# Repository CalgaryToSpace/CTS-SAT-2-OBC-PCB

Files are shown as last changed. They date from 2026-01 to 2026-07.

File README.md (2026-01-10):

# CTS-SAT-2-OBC-PCB

This is the design repository for the CTS-SAT-2 onboard computer (OBC) PCB.

This OBC is host to an STM32 and several flash chips, and interfaces with all other electrical components on the 3U CubeSat.

## Repository Contents

* OBC PCB (KiCad; in progress) 
* STM32CubeIDE Pinout/IOC configuration (not yet done)

## Contributors

* Nadeem M ([DeemDeem52](https://github.com/DeemDeem52))
* Others

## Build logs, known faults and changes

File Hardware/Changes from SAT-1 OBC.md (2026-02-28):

# Changes from SAT-1 OBC

* RP2040 added as co-processor. ANT connections are through this processor instead of through the STM32.
   * SPI1 on the STM32 has been re-assigned to the RP2040 for simplicity of notation, and SPI2 on the STM32 has been assigned to the flash memory / FRAM (though the GPIO chip-select lines remain the same).
		* (Rationale: this way SPI1 on the RP2040 is connected to SPI1 of the STM32. SPI0 on the RP2040 is not connected to anything.)
   * The RP2040 has been assigned its own oscillator and flash memory. This could change in future.
   * ANT I2C2 and I2C3 lines from the STM32 have been reassigned to I2C0 and I2C1 from the RP2040.
		* To simplify notation, ADCS I2C1 has been reassigned to I2C2, and Temperature Sensor I2C4 had been reassigned to I2C3.
		* (Rationale: this way there is only one each of I2C0, 1, 2, and 3 on the board instead of having 2x I2C1 connected to different things)
* Temperature sensor STDS75 has gone obsolete. Using manufacturer-recommended replacement STTS22H instead.
* FRAM memory chip CY15B108QN-40LPXI has gone obsolete. Chips have been removed because they were unused in CTS-SAT-1. 
* A connector (Picoblade, 4-wide) has been added for the Optical Downlink Payload, which communicates via USART2. 
* Header pins for jumpers have been placed on the 3V3, 5V, and 12V lines where they enter the OBC to allow for easier current measurement.
* On the PC104 header, H1 pins 33 and 35 have been assigned to the ADCS UART connections. They are presently unconnected.
* STM32 25MHz clock ECS-TXO-2520-33-250-AN-TR originally had no stock available at DigiKey, but now has 515. No changes have been made to this.
* STM32 Reset Switch KH-6X6X4.3H-STM is very difficult to find. Replacing with C&K PTS526SK15SMTR2-LFS, which is available at DigiKey.

# Info from Design Reviews
* MPI expects to downlink a lot of data, which might require additional or larger flash memory modules. 
* DP on RP2040 to reset it to a known state in case of bad code?

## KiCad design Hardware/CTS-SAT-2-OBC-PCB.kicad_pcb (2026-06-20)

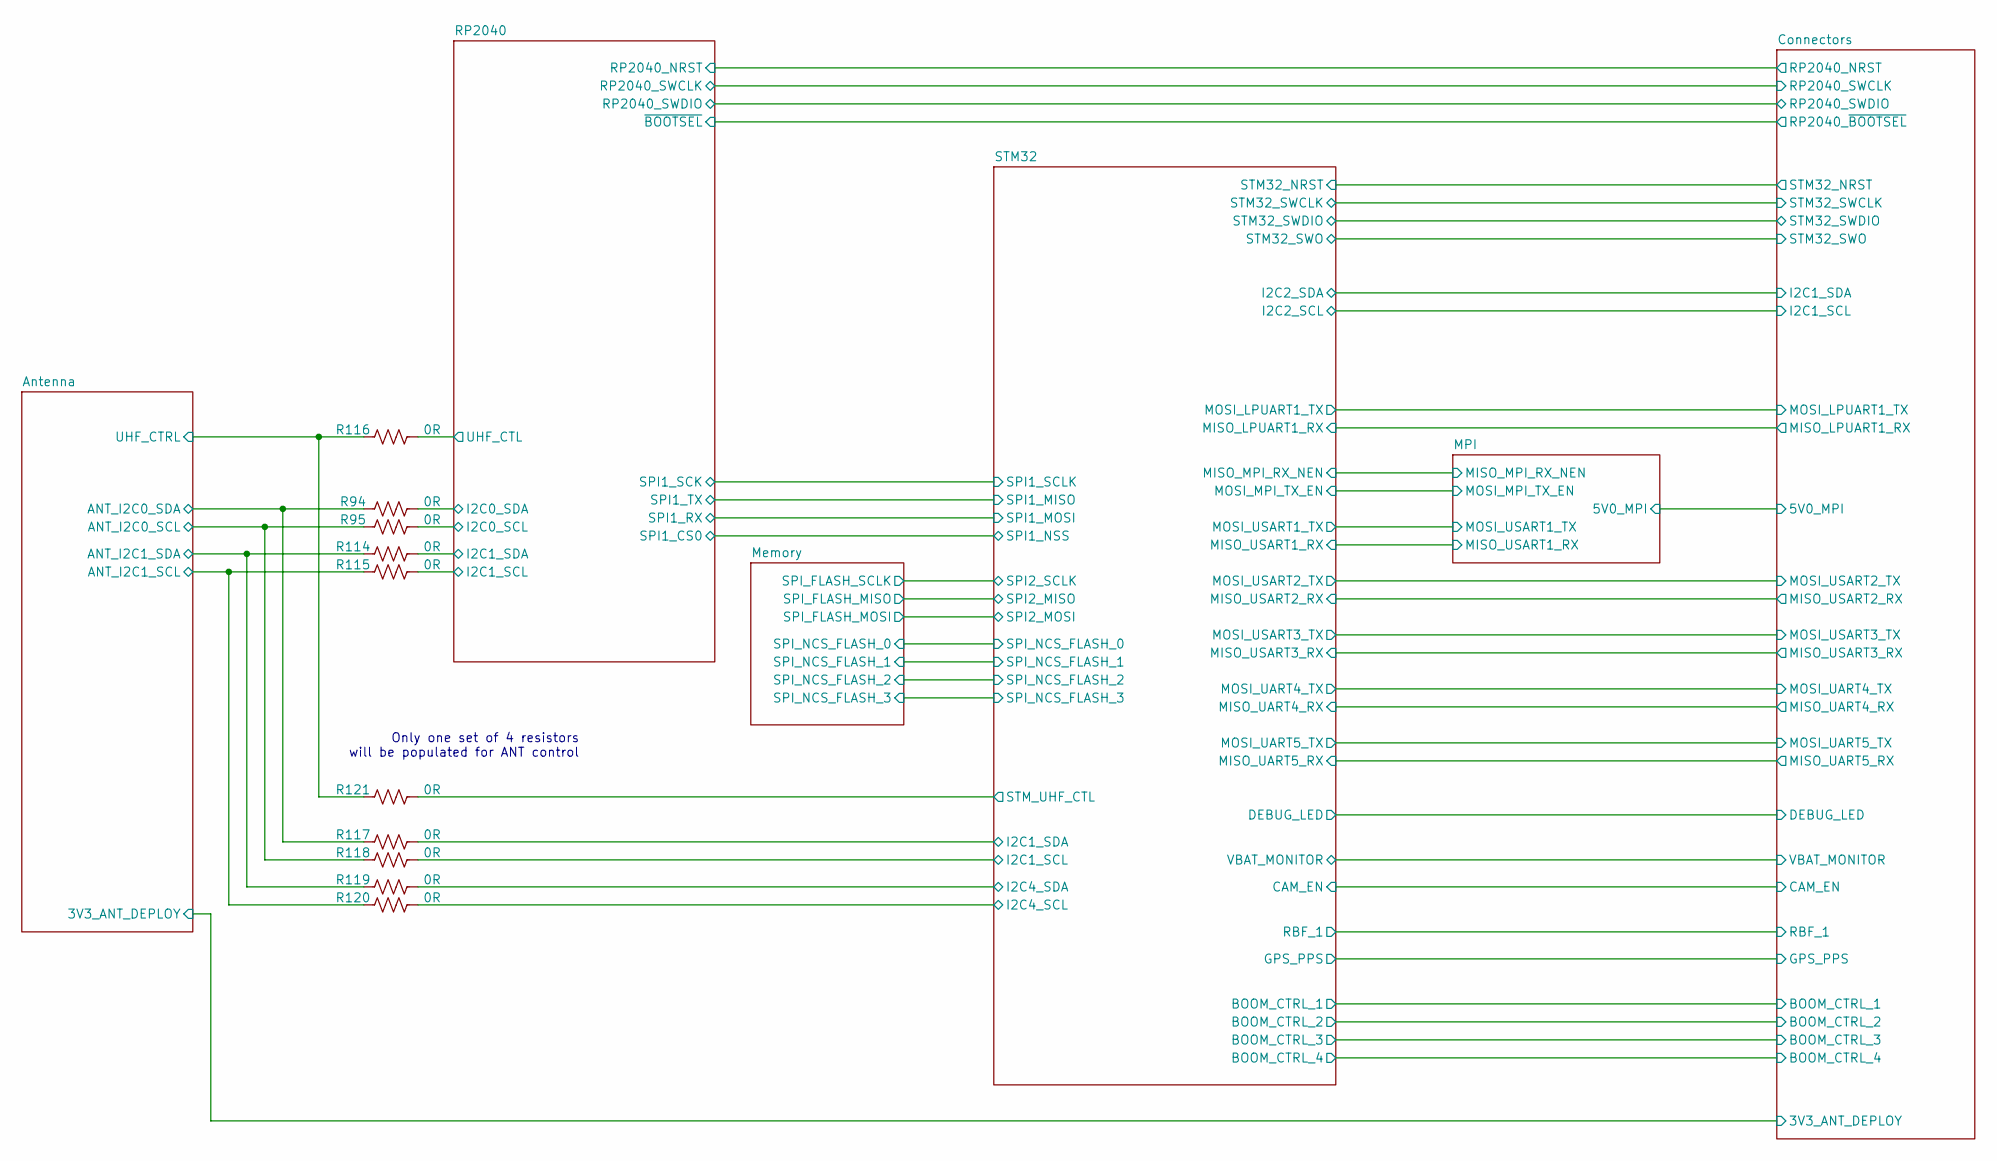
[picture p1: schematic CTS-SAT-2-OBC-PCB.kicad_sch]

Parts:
R94, R95, R114, R115, R116, R117, R118, R119, R120, R121: 0R; R_0603_1608Metric

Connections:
/Antenna/ANT_I2C0_SCL: R95.1, R118.1; also elsewhere on the board
/Antenna/ANT_I2C0_SDA: R94.1, R117.1; also elsewhere on the board
/Antenna/ANT_I2C1_SCL: R115.1, R120.1; also elsewhere on the board
/Antenna/ANT_I2C1_SDA: R114.1, R119.1; also elsewhere on the board
/Antenna/UHF_CTRL: R116.1, R121.1; also elsewhere on the board
/RP2040/I2C0_SCL: R95.2; also elsewhere on the board
/RP2040/I2C0_SDA: R94.2; also elsewhere on the board
/RP2040/I2C1_SCL: R115.2; also elsewhere on the board
/RP2040/I2C1_SDA: R114.2; also elsewhere on the board
/RP2040/UHF_CTL: R116.2; also elsewhere on the board
/STM32/I2C1_SCL: R118.2; also elsewhere on the board
/STM32/I2C1_SDA: R117.2; also elsewhere on the board
/STM32/I2C4_SCL: R120.2; also elsewhere on the board
/STM32/I2C4_SDA: R119.2; also elsewhere on the board
/STM32/STM_UHF_CTL: R121.2

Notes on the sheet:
Only one set of 4 resistors will be populated for ANT control

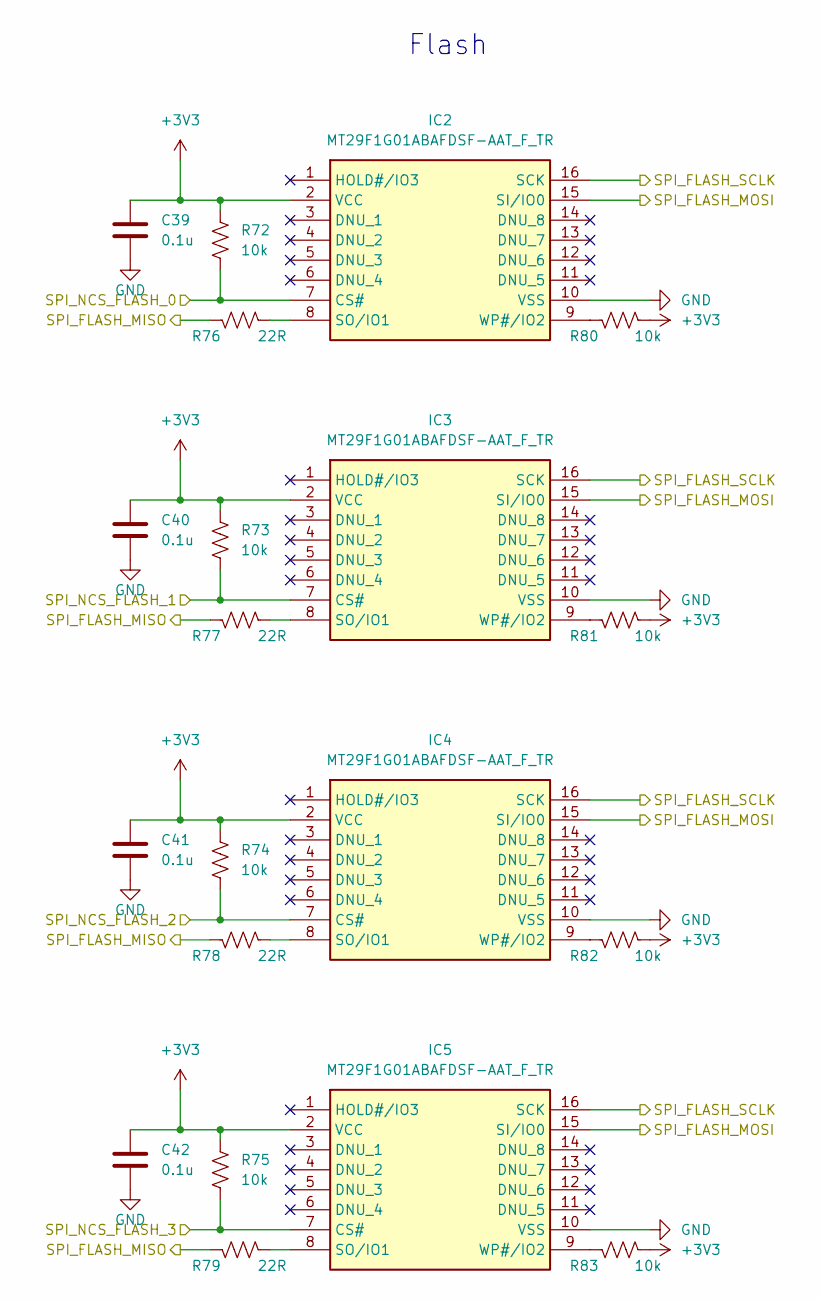
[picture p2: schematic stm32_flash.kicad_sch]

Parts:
C39, C40, C41, C42: 0.1u; C_0603_1608Metric
IC2, IC3, IC4, IC5: MT29F1G01ABAFDSF-AAT_F_TR; SOIC-16W_7.5x10.3mm_P1.27mm; Mouser Part Number 340-312330-REEL
R72, R73, R74, R75, R80, R81, R82, R83: 10k; R_0603_1608Metric
R76, R77, R78, R79: 22R; R_0603_1608Metric

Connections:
+3V3: C39.2, C40.2, C41.2, C42.2, IC2.2 (VCC), IC3.2 (VCC), IC4.2 (VCC), IC5.2 (VCC), R72.1, R73.1, R74.1, R75.1, R80.2, R81.2, R82.2, R83.2; also elsewhere on the board
/Memory/SPI_FLASH_MISO: R76.2, R77.2, R78.2, R79.2; also elsewhere on the board
/Memory/SPI_FLASH_MOSI: IC2.15 (SI/IO0), IC3.15 (SI/IO0), IC4.15 (SI/IO0), IC5.15 (SI/IO0); also elsewhere on the board
/Memory/SPI_FLASH_SCLK: IC2.16 (SCK), IC3.16 (SCK), IC4.16 (SCK), IC5.16 (SCK); also elsewhere on the board
/Memory/SPI_NCS_FLASH_0: IC2.7 (CS#), R72.2; also elsewhere on the board
/Memory/SPI_NCS_FLASH_1: IC3.7 (CS#), R73.2; also elsewhere on the board
/Memory/SPI_NCS_FLASH_2: IC4.7 (CS#), R74.2; also elsewhere on the board
/Memory/SPI_NCS_FLASH_3: IC5.7 (CS#), R75.2; also elsewhere on the board
GND: C39.1, C40.1, C41.1, C42.1, IC2.10 (VSS), IC3.10 (VSS), IC4.10 (VSS), IC5.10 (VSS); also elsewhere on the board
unnamed: IC2.8 (SO/IO1), R76.1
unnamed: IC2.9 (WP#/IO2), R80.1
unnamed: IC3.8 (SO/IO1), R77.1
unnamed: IC3.9 (WP#/IO2), R81.1
unnamed: IC4.8 (SO/IO1), R78.1
unnamed: IC4.9 (WP#/IO2), R82.1
unnamed: IC5.8 (SO/IO1), R79.1
unnamed: IC5.9 (WP#/IO2), R83.1

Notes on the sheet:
Flash

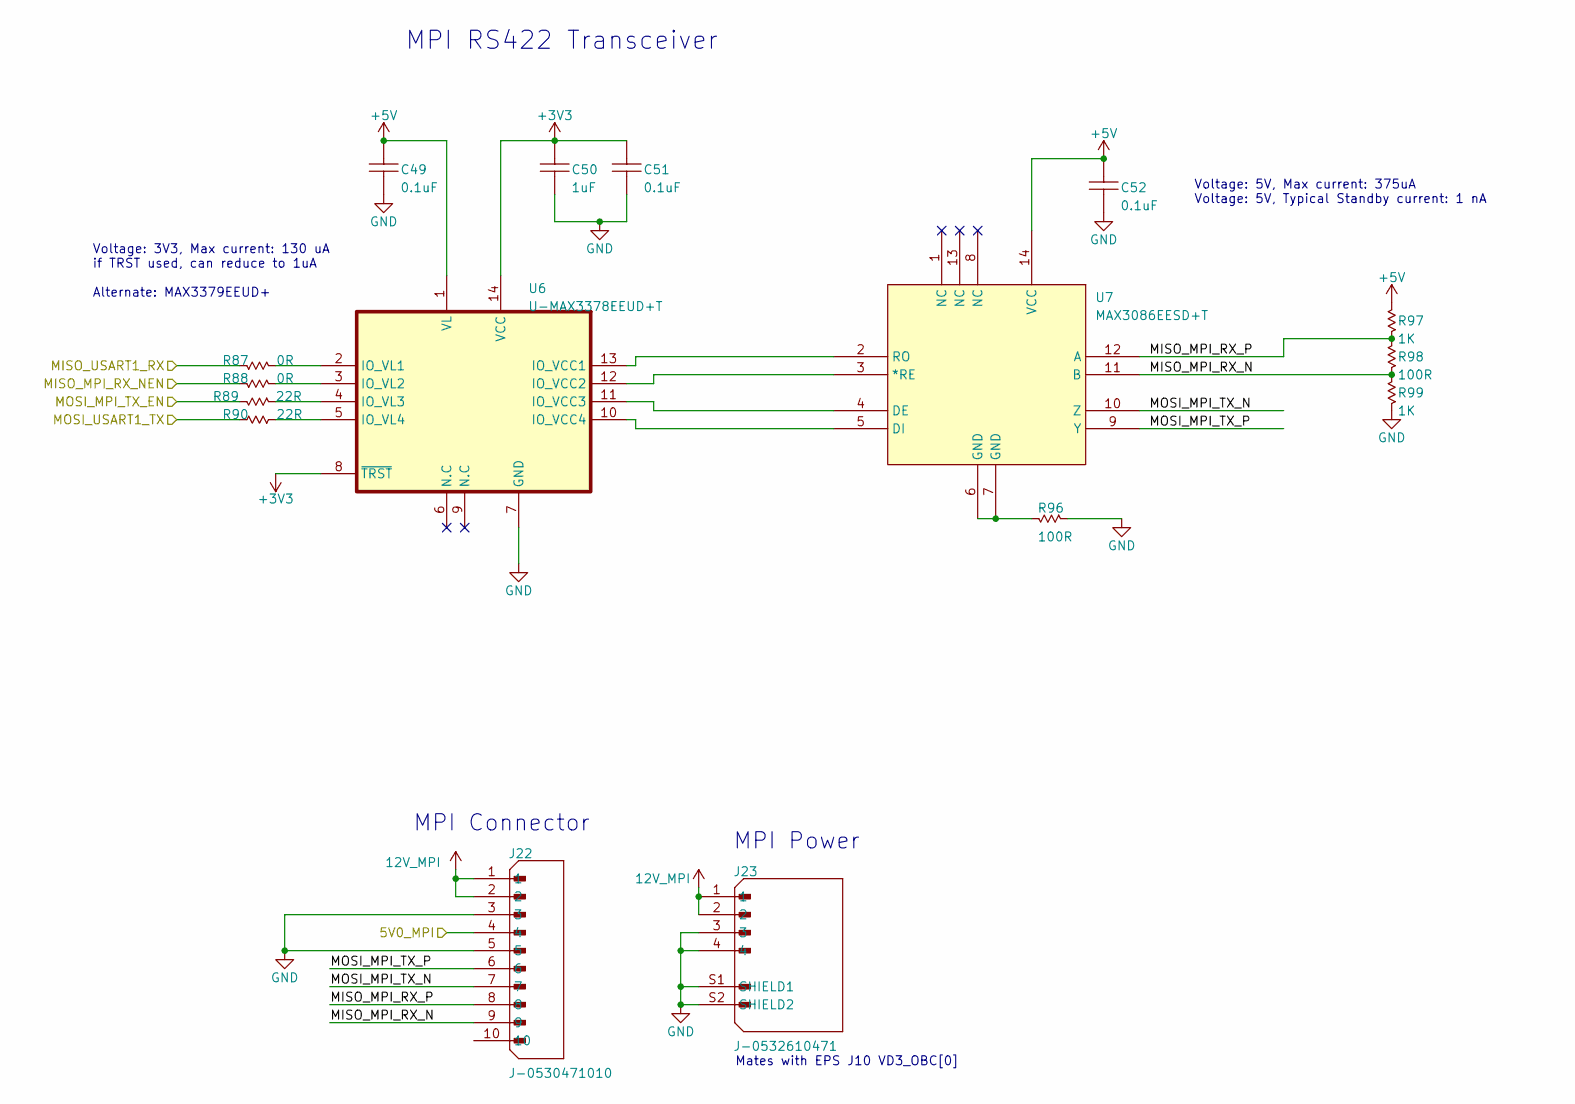
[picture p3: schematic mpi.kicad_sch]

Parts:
C49, C51, C52: 0.1uF; C_0603_1608Metric; RATED VOLTAGE 25; MANUFACTURER PART # GCJ188R71E104KA12D
C50: 1uF; C_0603_1608Metric; MANUFACTURER PART # CC0603KRX7R8BB105
J22: J-0530471010; MANUFACTURER PART # 0530471010
J23: J-0532610471; J-53261-0471; MANFACTURER PART # 0532610471
R87, R88: 0R; R_0603_1608Metric; MANUFACTURER PART # RMCF0603ZT0R00
R89, R90: 22R; R_0603_1608Metric; MANUFACTURER PART # RR0816Q-220-D
R96, R98: 100R; R_0603_1608Metric; MANUFACTURER PART # RR08P100DCT-ND
R97, R99: 1K; R_0603_1608Metric; MANUFACTURER PART # CPF0603F1K0C1
U6: U-MAX3378EEUD+T; MANUFACTURER PART # MAX3378EEUD+T; LCSC PART # C143441
U7: MAX3086EESD+T; U-MAX3086EESD+T; MANUFACTURER PART # MAX3086EESD+T; LCSC PART # C2671104

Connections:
12V_MPI: J22.1, J22.2, J23.1, J23.2
+3V3: C50.2, C51.1, U6.8 (~TRST), U6.14 (VCC); also elsewhere on the board
+5V: C49.1, C52.1, R97.2, U6.1 (VL), U7.14 (VCC); also elsewhere on the board
/Connectors/5V0_MPI: J22.4; also elsewhere on the board
/MPI/MISO_MPI_RX_N: J22.9, R98.1, R99.2, U7.11 (B)
/MPI/MISO_MPI_RX_NEN: R88.1; also elsewhere on the board
/MPI/MISO_MPI_RX_P: J22.8, R97.1, R98.2, U7.12 (A)
/MPI/MISO_USART1_RX: R87.1; also elsewhere on the board
/MPI/MOSI_MPI_TX_EN: R89.2; also elsewhere on the board
/MPI/MOSI_MPI_TX_N: J22.7, U7.10 (Z)
/MPI/MOSI_MPI_TX_P: J22.6, U7.9 (Y)
/MPI/MOSI_USART1_TX: R90.2; also elsewhere on the board
GND: C49.2, C50.1, C51.2, C52.2, J22.3, J22.5, J23.3, J23.4, J23.S1 (SHIELD1), J23.S2 (SHIELD2), R96.1, R99.1, U6.7 (GND); also elsewhere on the board
unnamed: R96.2, U7.6 (GND), U7.7 (GND)
unnamed: U6.13 (IO_VCC1), U7.2 (RO)
unnamed: U6.12 (IO_VCC2), U7.3 (*RE)
unnamed: U6.11 (IO_VCC3), U7.4 (DE)
unnamed: U6.10 (IO_VCC4), U7.5 (DI)
unnamed: R87.2, U6.2 (IO_VL1)
unnamed: R88.2, U6.3 (IO_VL2)
unnamed: R89.1, U6.4 (IO_VL3)
unnamed: R90.1, U6.5 (IO_VL4)

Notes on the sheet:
Voltage: 3V3, Max current: 130 uA if TRST used, can reduce to 1uA Alternate: MAX3379EEUD+
Voltage: 5V, Max current: 375uA Voltage: 5V, Typical Standby current: 1 nA
Mates with EPS J10 VD3_OBC[0]
MPI Connector
MPI Power
MPI RS422 Transceiver

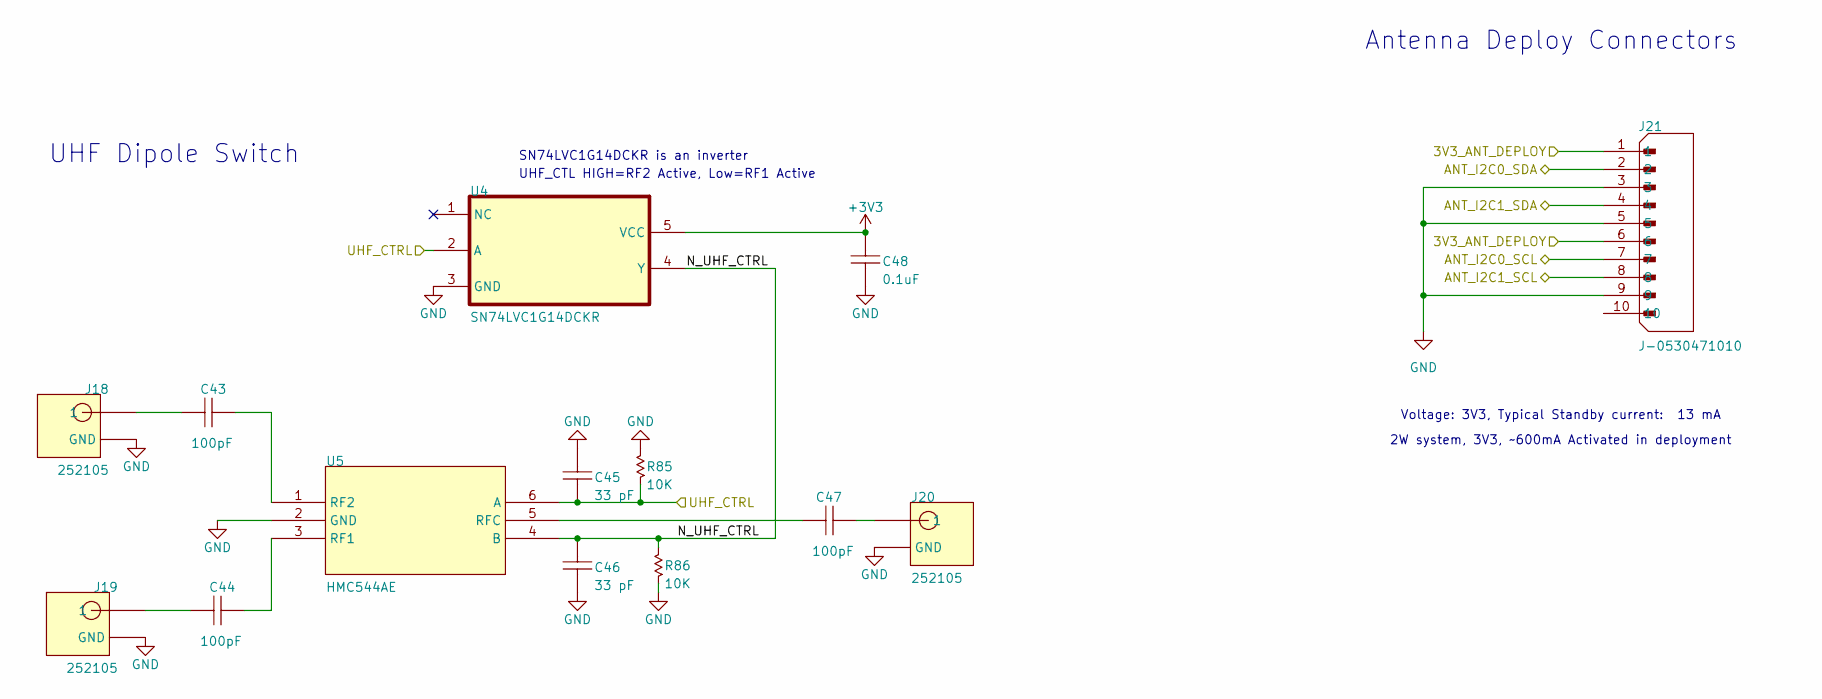
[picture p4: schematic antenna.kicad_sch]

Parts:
C43, C44, C47: 100pF; C_0603_1608Metric; MANUFACTURER PART # CC0603KRX7R9BB101
C45, C46: 33 pF; C_0603_1608Metric; MANUFACTURER PART # C0603C330K5RAC7867
C48: 0.1uF; C_0603_1608Metric; RATED VOLTAGE 25; MANUFACTURER PART # GCJ188R71E104KA12D
J18, J19, J20: 252105; J-252105; MANUFACTURER PART # 252105
J21: J-0530471010; MANUFACTURER PART # 0530471010
R85, R86: 10K; R_0603_1608Metric; MANUFACTURER PART # CPF0603B10KE
U4: SN74LVC1G14DCKR; U-SN74LVC1G14DCKR; MANUFACTURER PART # SN74LVC1G14DCKR; LCSC PART # C35740
U5: HMC544AE; U-HMC544AETR; MANUFACTURER PART # HMC544AETR; LCSC PART # C579555

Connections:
+3V3: C48.2, U4.5 (VCC); also elsewhere on the board
/Antenna/3V3_ANT_DEPLOY: J21.1, J21.6; also elsewhere on the board
/Antenna/ANT_I2C0_SCL: J21.7; also elsewhere on the board
/Antenna/ANT_I2C0_SDA: J21.2; also elsewhere on the board
/Antenna/ANT_I2C1_SCL: J21.8; also elsewhere on the board
/Antenna/ANT_I2C1_SDA: J21.4; also elsewhere on the board
/Antenna/N_UHF_CTRL: C46.2, R86.2, U4.4 (Y), U5.4 (B)
/Antenna/UHF_CTRL: C45.1, R85.1, U4.2 (A), U5.6 (A); also elsewhere on the board
GND: C45.2, C46.1, C48.1, J18.0 (GND), J19.0 (GND), J20.0 (GND), J21.3, J21.5, J21.9, R85.2, R86.1, U4.3 (GND), U5.2 (GND); also elsewhere on the board
unnamed: C43.1, J18.1
unnamed: C44.1, J19.1
unnamed: C47.2, J20.1
unnamed: C44.2, U5.3 (RF1)
unnamed: C43.2, U5.1 (RF2)
unnamed: C47.1, U5.5 (RFC)

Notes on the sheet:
Antenna Deploy Connectors
Voltage: 3V3, Typical Standby current: 13 mA
SN74LVC1G14DCKR is an inverter
UHF Dipole Switch
UHF_CTL HIGH=RF2 Active, Low=RF1 Active
2W system, 3V3, ~600mA Activated in deployment

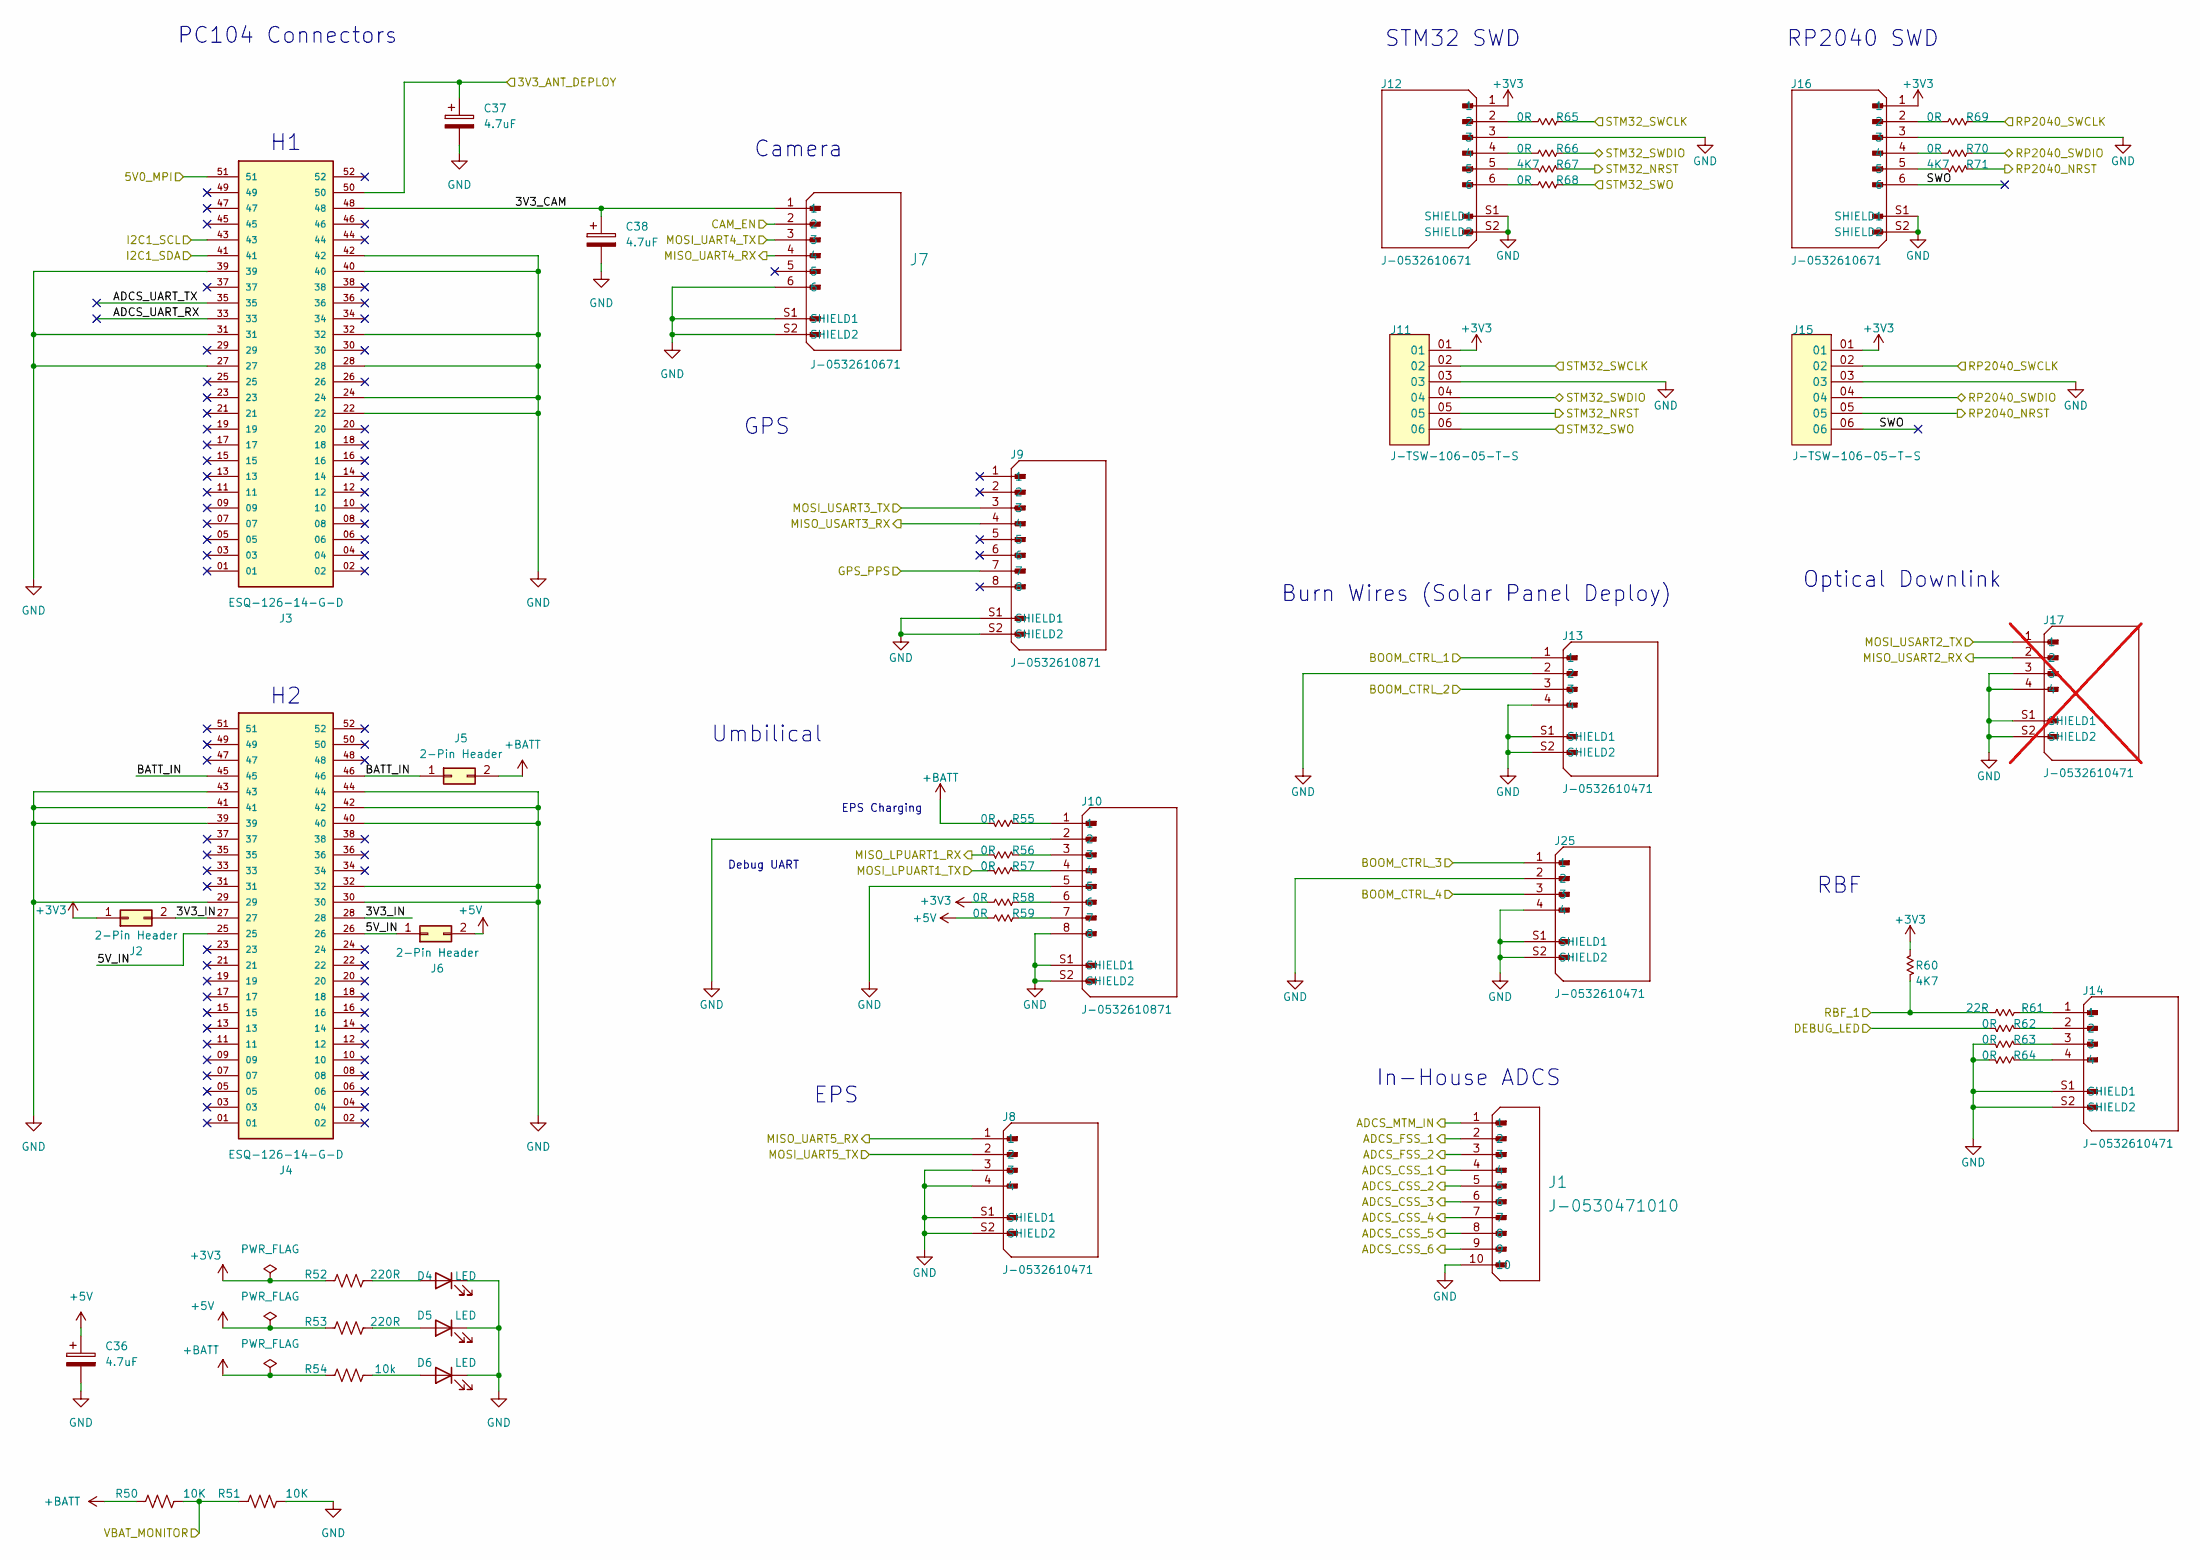
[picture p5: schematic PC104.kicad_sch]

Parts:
C36, C37, C38: 4.7uF; C_1206_3216Metric
D4, D5, D6: LED; D-SML-D12U1WT86
J1: J-0530471010; Manufacturer Part # 0530471010
J2, J5, J6: 2-Pin Header; PinHeader_1x02_P1.27mm_Vertical
J3, J4: ESQ-126-14-G-D; SAMTEC_ESQ-126-14-G-D; PARTREV R
J7: J-0532610671; Manfacturer Part # 0532610671
J8, J13, J14, J25: J-0532610471; J-53261-0471; MANFACTURER PART # 0532610471
J9, J10: J-0532610871; J-532610871; MANFACTURER PART # 0532610871
J11, J15: J-TSW-106-05-T-S; MANUFACTURER PART # TSW-106-05-T-S
J12, J16: J-0532610671; MANFACTURER PART # 0532610671
J17: J-0532610471; J-53261-0471; MANFACTURER PART # 0532610471; not fitted
R50, R51: 10K; R_0603_1608Metric
R52, R53: 220R; R_0603_1608Metric
R54: 10k; R_0603_1608Metric
R55, R56, R57, R58, R59, R62, R63, R64, R65, R66, R68, R69, R70: 0R; R_0603_1608Metric; MANUFACTURER PART # RMCF0603ZT0R00
R60, R67, R71: 4K7; R_0603_1608Metric; MANUFACTURER PART # CR0603-FX-4701ELF
R61: 22R; R_0603_1608Metric; MANUFACTURER PART # RR0816Q-220-D

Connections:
+3V3: J2.1, J11.01, J12.1, J15.01, J16.1, R52.1, R58.2, R60.2; also elsewhere on the board
+5V: C36.1, J6.2, R53.1, R59.2; also elsewhere on the board
+BATT: J5.2, R50.1, R54.1, R55.1
/Antenna/3V3_ANT_DEPLOY: C37.1, J3.50; also elsewhere on the board
/Connectors/3V3_CAM: C38.1, J3.48, J7.1
/Connectors/3V3_IN: J2.2, J4.27, J4.28
/Connectors/5V0_MPI: J3.51; also elsewhere on the board
/Connectors/5V_IN: J4.25, J4.26, J6.1
/Connectors/ADCS_CSS_1: J1.4
/Connectors/ADCS_CSS_2: J1.5
/Connectors/ADCS_CSS_3: J1.6
/Connectors/ADCS_CSS_4: J1.7
/Connectors/ADCS_CSS_5: J1.8
/Connectors/ADCS_CSS_6: J1.9
/Connectors/ADCS_FSS_1: J1.2
/Connectors/ADCS_FSS_2: J1.3
/Connectors/ADCS_MTM_IN: J1.1
/Connectors/ADCS_UART_RX: J3.33
/Connectors/ADCS_UART_TX: J3.35
/Connectors/BATT_IN: J4.45, J4.46, J5.1
/Connectors/BOOM_CTRL_1: J13.1; also elsewhere on the board
/Connectors/BOOM_CTRL_2: J13.3; also elsewhere on the board
/Connectors/BOOM_CTRL_3: J25.1; also elsewhere on the board
/Connectors/BOOM_CTRL_4: J25.3; also elsewhere on the board
/Connectors/CAM_EN: J7.2; also elsewhere on the board
/Connectors/DEBUG_LED: R62.1; also elsewhere on the board
/Connectors/GPS_PPS: J9.7; also elsewhere on the board
/Connectors/MISO_LPUART1_RX: R56.1; also elsewhere on the board
/Connectors/MISO_UART4_RX: J7.4; also elsewhere on the board
/Connectors/MISO_UART5_RX: J8.1; also elsewhere on the board
/Connectors/MISO_USART3_RX: J9.4; also elsewhere on the board
/Connectors/MOSI_LPUART1_TX: R57.1; also elsewhere on the board
/Connectors/MOSI_UART4_TX: J7.3; also elsewhere on the board
/Connectors/MOSI_UART5_TX: J8.2; also elsewhere on the board
/Connectors/MOSI_USART3_TX: J9.3; also elsewhere on the board
/Connectors/RBF_1: R60.1, R61.1; also elsewhere on the board
/Connectors/RP2040_NRST: J15.05, R71.1; also elsewhere on the board
/Connectors/RP2040_SWCLK: J15.02, R69.1; also elsewhere on the board
/Connectors/RP2040_SWDIO: J15.04, R70.1; also elsewhere on the board
/Connectors/STM32_NRST: J11.05, R67.1; also elsewhere on the board
/Connectors/STM32_SWCLK: J11.02, R65.1; also elsewhere on the board
/Connectors/STM32_SWDIO: J11.04, R66.1; also elsewhere on the board
/Connectors/STM32_SWO: J11.06, R68.1; also elsewhere on the board
/Connectors/SWO: J15.06, J16.6
/Connectors/VBAT_MONITOR: R50.2, R51.1; also elsewhere on the board
/STM32/I2C2_SCL: J3.43; also elsewhere on the board
/STM32/I2C2_SDA: J3.41; also elsewhere on the board
GND: C36.2, C37.2, C38.2, D4.1 (K), D5.1 (K), D6.1 (K), J1.10, J3.22, J3.24, J3.27, J3.28, J3.31, J3.32, J3.39, J3.40, J3.42, J4.29, J4.30, J4.32, J4.39, J4.40, J4.41, J4.42, J4.43, J4.44, J7.6, J7.S1 (SHIELD1), J7.S2 (SHIELD2), J8.3, J8.4, J8.S1 (SHIELD1), J8.S2 (SHIELD2), J9.S1 (SHIELD1), J9.S2 (SHIELD2), J10.2, J10.5, J10.8, J10.S1 (SHIELD1), J10.S2 (SHIELD2), J11.03, J12.3, J12.S1 (SHIELD1), J12.S2 (SHIELD2), J13.2, J13.4, J13.S1 (SHIELD1), J13.S2 (SHIELD2), J14.S1 (SHIELD1), J14.S2 (SHIELD2), J15.03, J16.3, J16.S1 (SHIELD1), J16.S2 (SHIELD2), J17.3, J17.4, J17.S1 (SHIELD1), J17.S2 (SHIELD2), J25.2, J25.4, J25.S1 (SHIELD1), J25.S2 (SHIELD2), R51.2, R63.1, R64.1; also elsewhere on the board
unnamed: D4.2 (A), R52.2
unnamed: D5.2 (A), R53.2
unnamed: D6.2 (A), R54.2
unnamed: J10.1, R55.2
unnamed: J10.3, R56.2
unnamed: J10.4, R57.2
unnamed: J10.6, R58.1
unnamed: J10.7, R59.1
unnamed: J12.2, R65.2
unnamed: J12.4, R66.2
unnamed: J12.5, R67.2
unnamed: J12.6, R68.2
unnamed: J14.1, R61.2
unnamed: J14.2, R62.2
unnamed: J14.3, R63.2
unnamed: J14.4, R64.2
unnamed: J16.2, R69.2
unnamed: J16.4, R70.2
unnamed: J16.5, R71.2

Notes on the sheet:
PC104 Connectors
RP2040 SWD
RBF
Debug UART
Burn Wires (Solar Panel Deploy)
Optical Downlink
Camera
GPS
EPS
In-House ADCS
Umbilical
EPS Charging
STM32 SWD

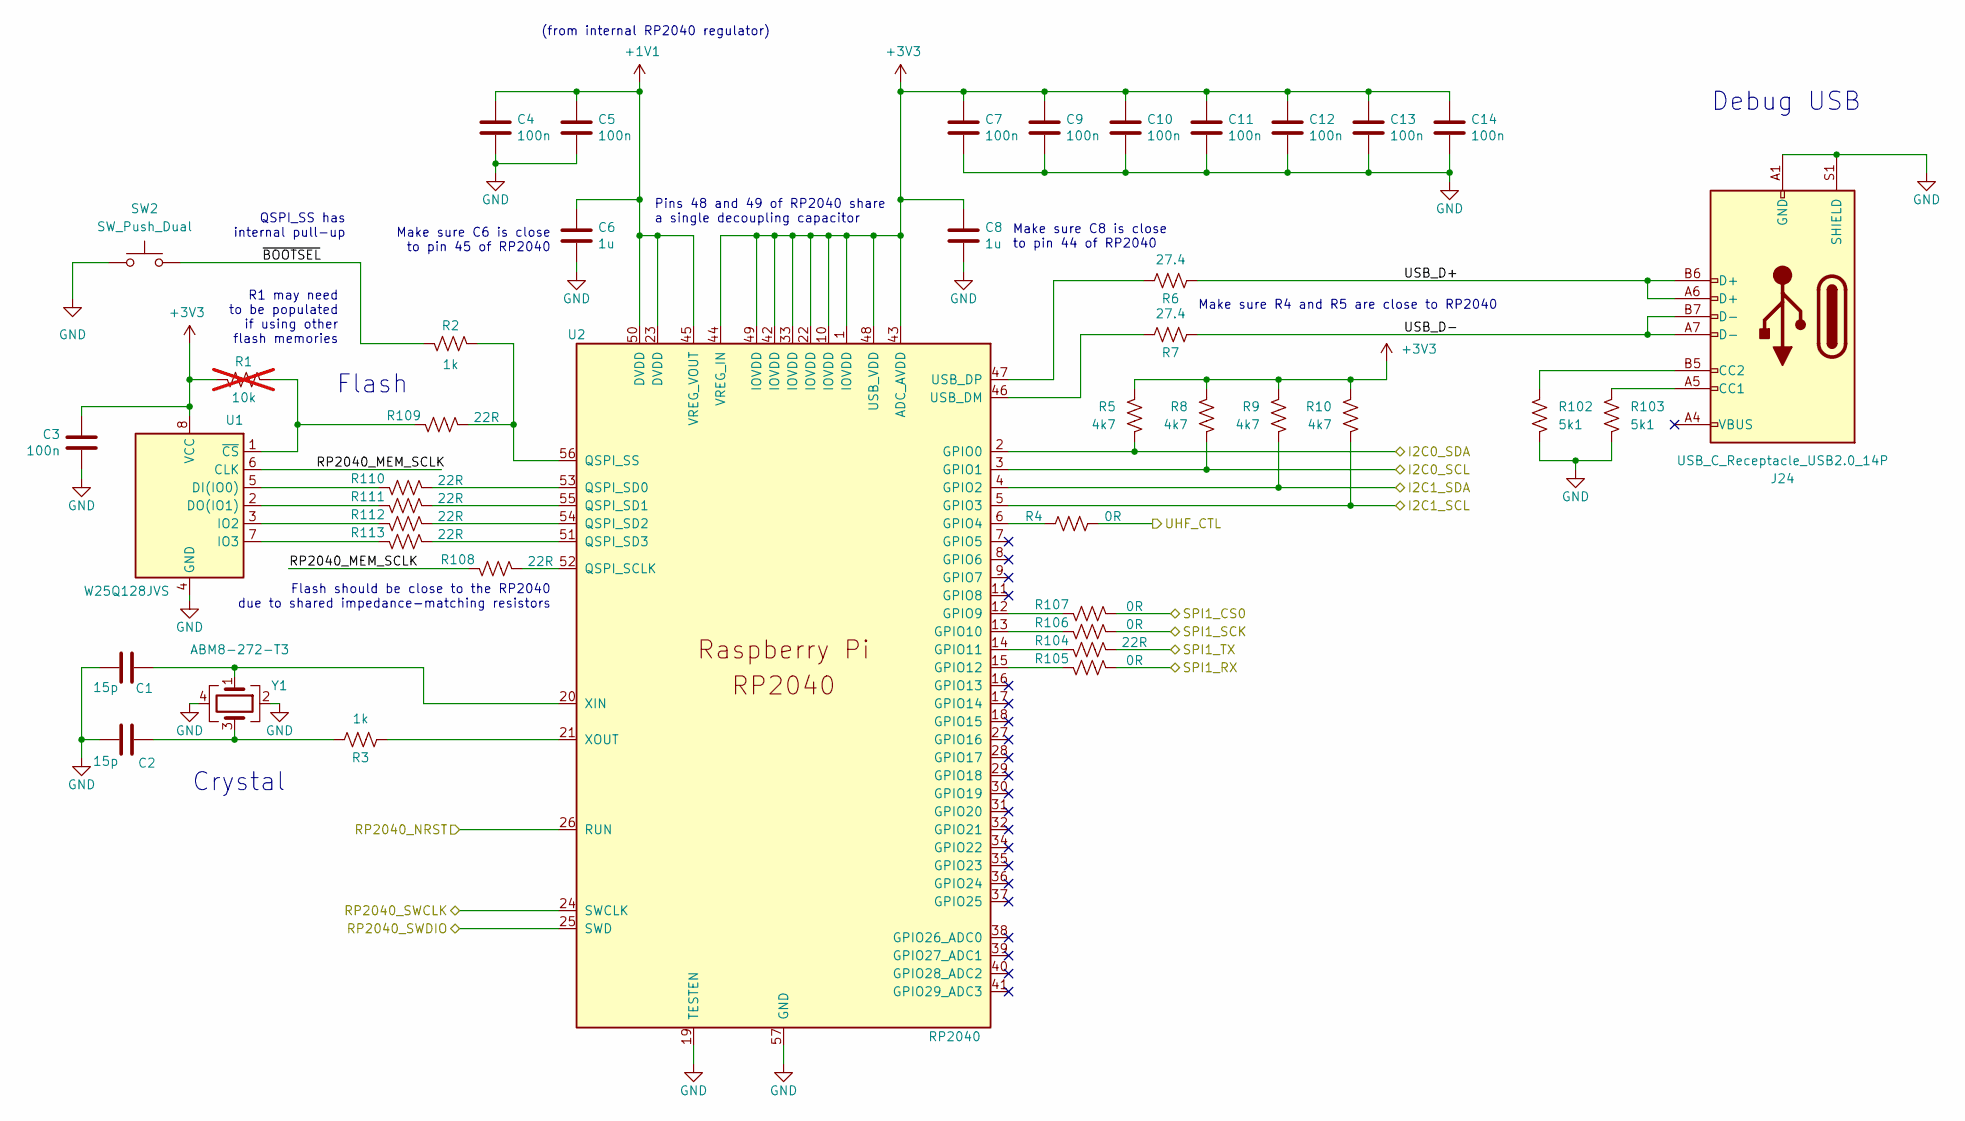
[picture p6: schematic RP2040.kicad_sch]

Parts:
C1, C2: 15p; C_0402_1005Metric
C3, C4, C5, C7, C9, C10, C11, C12, C13, C14: 100n; C_0402_1005Metric
C6, C8: 1u; C_0402_1005Metric
J24: USB_C_Receptacle_USB2.0_14P; USB_C_Receptacle_JAE_DX07S024WJ3R400
R1: 10k; R_0402_1005Metric; not fitted
R2, R3: 1k; R_0402_1005Metric
R4, R105, R106, R107: 0R; R_0603_1608Metric
R5, R8, R9, R10: 4k7; R_0603_1608Metric
R6, R7: 27.4; R_0402_1005Metric
R102, R103: 5k1; R_0603_1608Metric
R104, R108, R109, R110, R111, R112, R113: 22R; R_0603_1608Metric
SW2: SW_Push_Dual; SMT_FS
U1: W25Q128JVS; SOIC-8_5.23x5.23mm_P1.27mm
U2: RP2040; RP2040-QFN-56
Y1: ABM8-272-T3; Crystal_SMD_3225-4Pin_3.2x2.5mm

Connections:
+1V1: C4.1, C5.1, C6.1, U2.23 (DVDD), U2.45 (VREG_VOUT), U2.50 (DVDD)
+3V3: C3.1, C7.1, C8.1, C9.1, C10.1, C11.1, C12.1, C13.1, C14.1, R1.2, R5.1, R8.1, R9.1, R10.1, U1.8 (VCC), U2.1 (IOVDD), U2.10 (IOVDD), U2.22 (IOVDD), U2.33 (IOVDD), U2.42 (IOVDD), U2.43 (ADC_AVDD), U2.44 (VREG_IN), U2.48 (USB_VDD), U2.49 (IOVDD); also elsewhere on the board
/Connectors/RP2040_NRST: U2.26 (RUN); also elsewhere on the board
/Connectors/RP2040_SWCLK: U2.24 (SWCLK); also elsewhere on the board
/Connectors/RP2040_SWDIO: U2.25 (SWD); also elsewhere on the board
/RP2040/I2C0_SCL: R8.2, U2.3 (GPIO1); also elsewhere on the board
/RP2040/I2C0_SDA: R5.2, U2.2 (GPIO0); also elsewhere on the board
/RP2040/I2C1_SCL: R10.2, U2.5 (GPIO3); also elsewhere on the board
/RP2040/I2C1_SDA: R9.2, U2.4 (GPIO2); also elsewhere on the board
/RP2040/RP2040_MEM_SCLK: R108.2, U1.6 (CLK)
/RP2040/SPI1_CS0: R107.1; also elsewhere on the board
/RP2040/SPI1_RX: R105.1; also elsewhere on the board
/RP2040/SPI1_SCK: R106.1; also elsewhere on the board
/RP2040/SPI1_TX: R104.1; also elsewhere on the board
/RP2040/UHF_CTL: R4.2; also elsewhere on the board
/RP2040/USB_D+: J24.A6 (D+), J24.B6 (D+), R6.1
/RP2040/USB_D-: J24.A7 (D-), J24.B7 (D-), R7.1
/RP2040/~BOOTSEL: R2.2, SW2.1
GND: C1.2, C2.2, C3.2, C4.2, C5.2, C6.2, C7.2, C8.2, C9.2, C10.2, C11.2, C12.2, C13.2, C14.2, J24.A1 (GND), J24.A12 (GND), J24.B1 (GND), J24.B12 (GND), J24.S1 (SHIELD), R102.2, R103.2, SW2.2, U1.4 (GND), U2.19 (TESTEN), U2.57 (GND), Y1.2, Y1.4; also elsewhere on the board
unnamed: C2.1, R3.2, Y1.3
unnamed: J24.A5 (CC1), R103.1
unnamed: J24.B5 (CC2), R102.1
unnamed: R110.2, U1.5 (DI(IO0))
unnamed: R111.2, U1.2 (DO(IO1))
unnamed: R112.2, U1.3 (IO2)
unnamed: R113.2, U1.7 (IO3)
unnamed: R1.1, R109.2, U1.1 (~CS)
unnamed: R4.1, U2.6 (GPIO4)
unnamed: R107.2, U2.12 (GPIO9)
unnamed: R106.2, U2.13 (GPIO10)
unnamed: R104.2, U2.14 (GPIO11)
unnamed: R105.2, U2.15 (GPIO12)
unnamed: R108.1, U2.52 (QSPI_SCLK)
unnamed: R110.1, U2.53 (QSPI_SD0)
unnamed: R111.1, U2.55 (QSPI_SD1)
unnamed: R112.1, U2.54 (QSPI_SD2)
unnamed: R113.1, U2.51 (QSPI_SD3)
unnamed: R2.1, R109.1, U2.56 (QSPI_SS)
unnamed: R7.2, U2.46 (USB_DM)
unnamed: R6.2, U2.47 (USB_DP)
unnamed: C1.1, U2.20 (XIN), Y1.1
unnamed: R3.1, U2.21 (XOUT)

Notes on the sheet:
Debug USB
Crystal
QSPI_SS has internal pull-up
Pins 48 and 49 of RP2040 share a single decoupling capacitor
Make sure R4 and R5 are close to RP2040
Make sure C6 is close to pin 45 of RP2040
(from internal RP2040 regulator)
R1 may need to be populated if using other flash memories
Flash should be close to the RP2040 due to shared impedance-matching resistors
Flash
Make sure C8 is close to pin 44 of RP2040

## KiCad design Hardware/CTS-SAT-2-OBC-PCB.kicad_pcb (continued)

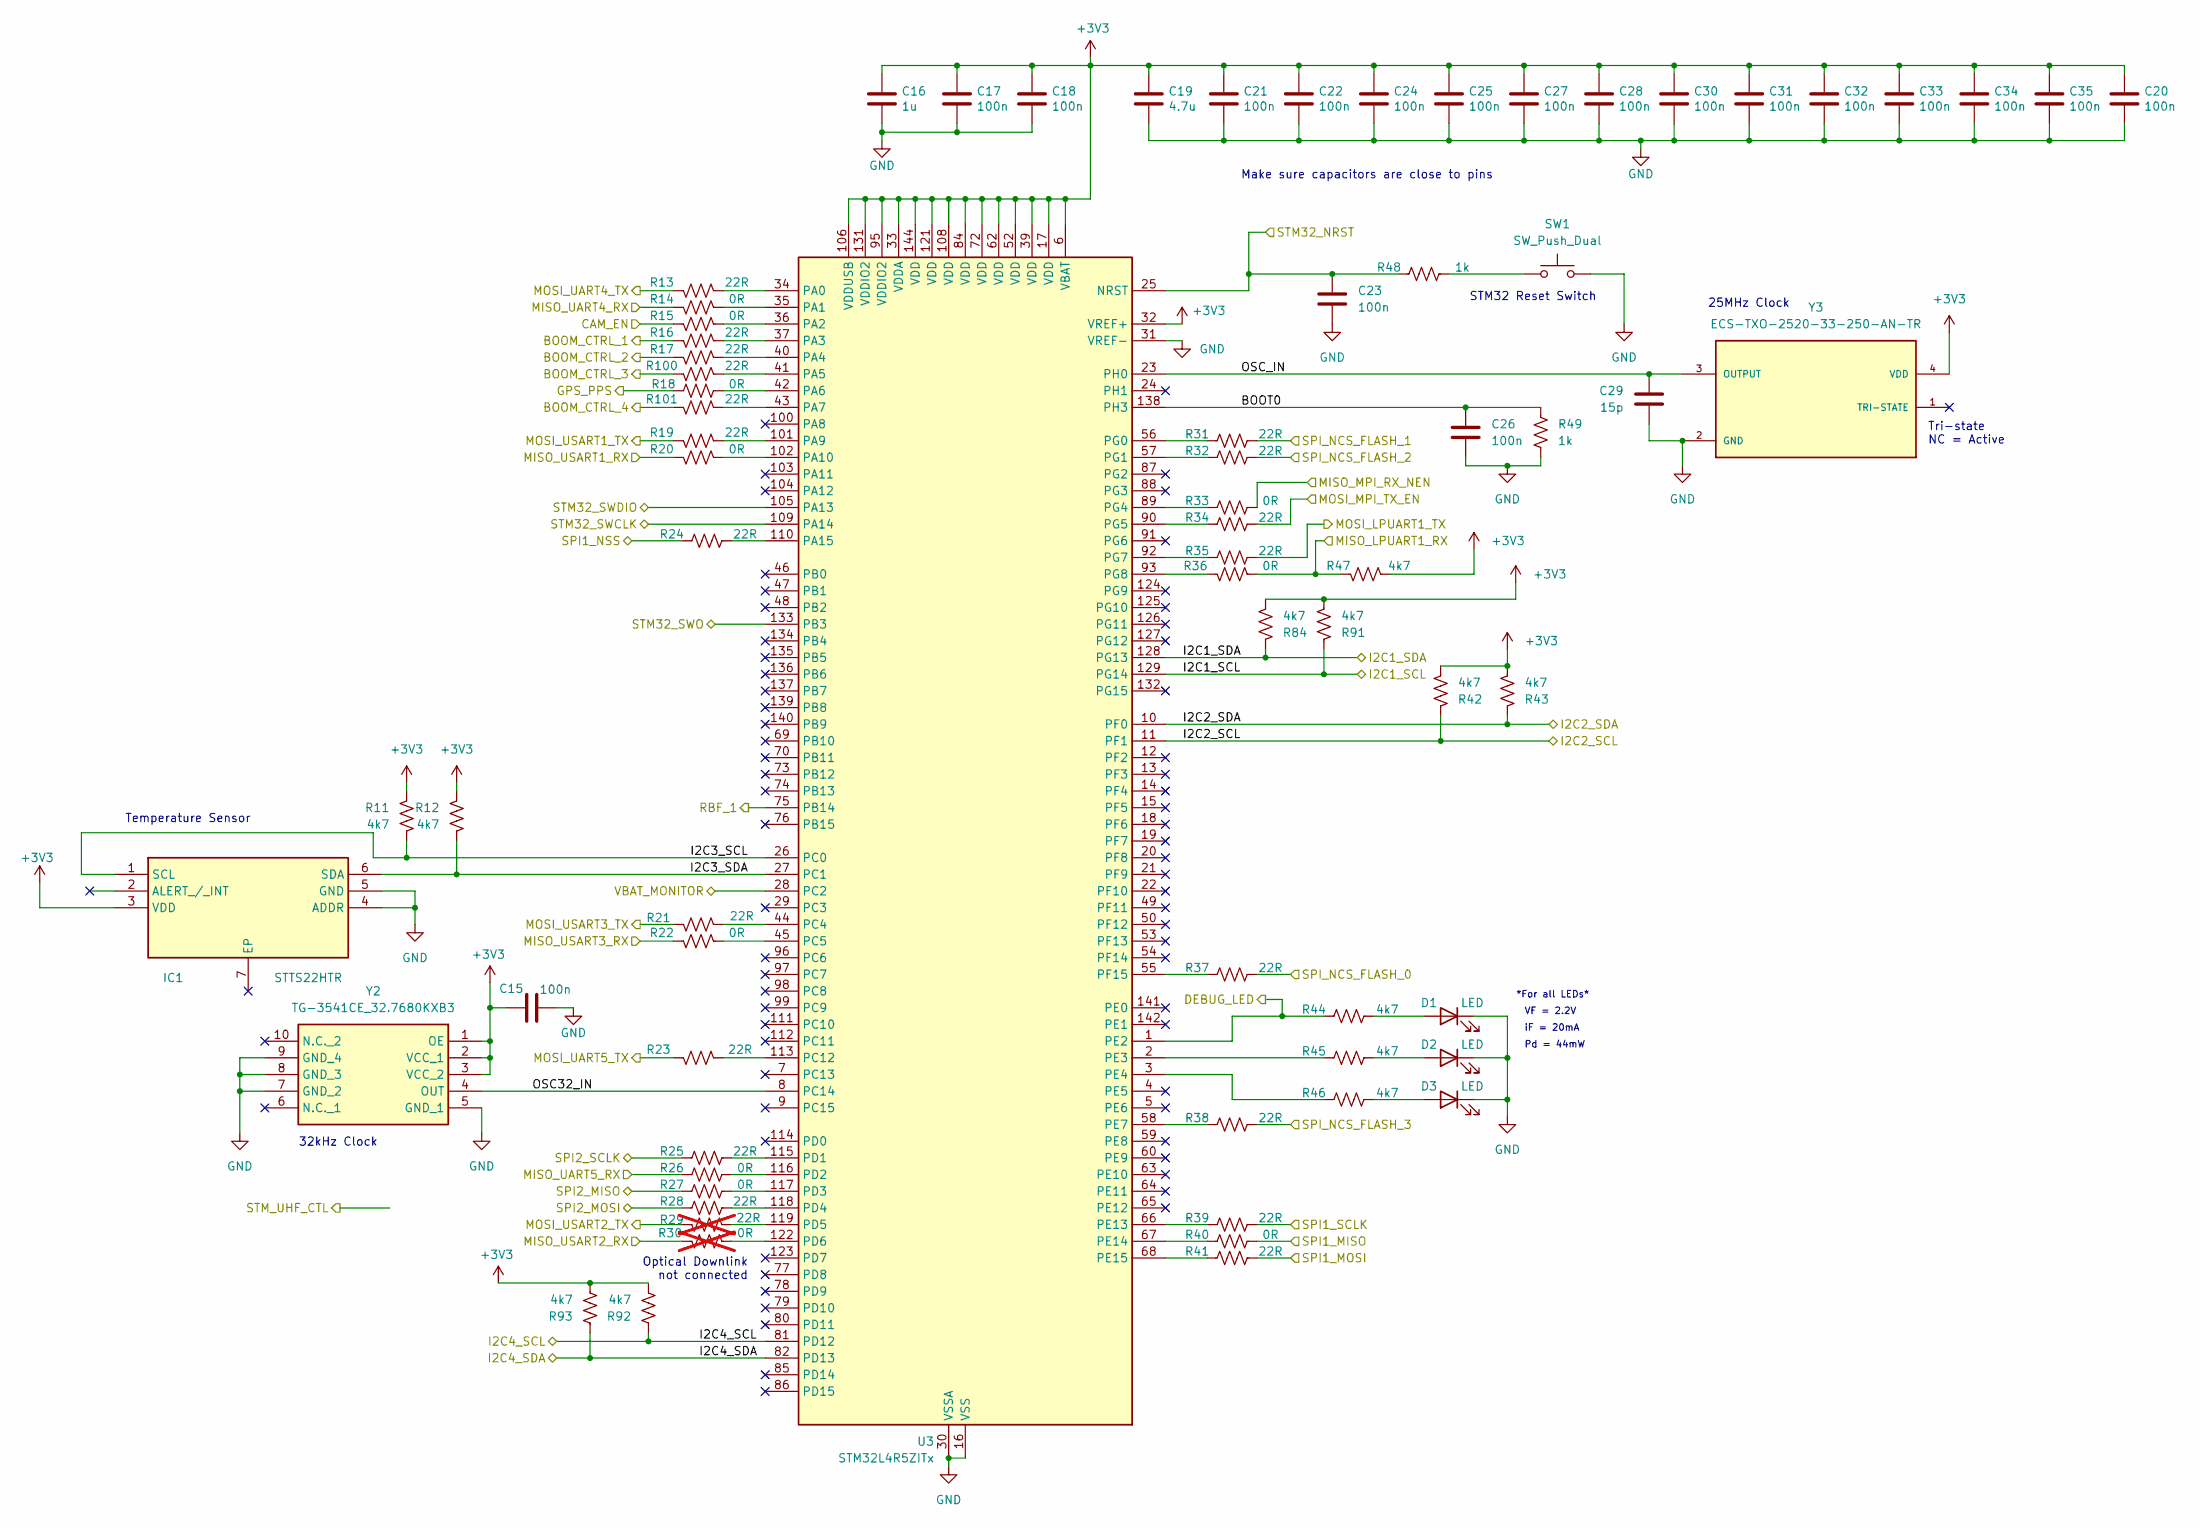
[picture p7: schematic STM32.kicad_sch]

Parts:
C15, C17, C18, C20, C21, C22, C24, C25, C27, C28, C30, C31, C32, C33, C34, C35: 100n; C_0402_1005Metric
C16: 1u; C_0402_1005Metric
C19: 4.7u; C_0402_1005Metric
C23, C26: 100n; C_0603_1608Metric
C29: 15p; C_0603_1608Metric
D1, D2, D3: LED; D-SML-D12U1WT86
IC1: STTS22HTR; SON65P200X200X55-7N-D; Manufacturer_Part_Number STTS22HTR; Mouser Part Number 511-STTS22HTR
R11, R12, R42, R43, R44, R45, R46, R47, R84, R91, R92, R93: 4k7; R_0603_1608Metric
R13, R16, R17, R19, R21, R23, R24, R25, R28, R31, R32, R34, R35, R37, R38, R39, R41, R100, R101: 22R; R_0603_1608Metric
R14, R15, R18, R20, R22, R26, R27, R33, R36, R40: 0R; R_0603_1608Metric
R29: 22R; R_0603_1608Metric; not fitted
R30: 0R; R_0603_1608Metric; not fitted
R48, R49: 1k; R_0603_1608Metric
SW1: SW_Push_Dual; SMT_FS
U3: STM32L4R5ZITx; LQFP-144_20x20mm_P0.5mm
Y2: TG-3541CE_32.7680KXB3; TG3541CE327680KXB3; Mouser Part Number 732-TG3541CE32768XB3
Y3: ECS-TXO-2520-33-250-AN-TR; OSC_ECS-TXO-2520-33-250-AN-TR; PARTREV 2017; DigiKey_Part_Number XC2258CT-ND

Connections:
+3V3: C15.1, C16.1, C17.1, C18.1, C19.1, C20.1, C21.1, C22.1, C24.1, C25.1, C27.1, C28.1, C30.1, C31.1, C32.1, C33.1, C34.1, C35.1, IC1.3 (VDD), R11.1, R12.1, R42.2, R43.2, R47.1, R84.2, R91.2, R92.2, R93.2, U3.6 (VBAT), U3.17 (VDD), U3.32 (VREF+), U3.33 (VDDA), U3.39 (VDD), U3.52 (VDD), U3.62 (VDD), U3.72 (VDD), U3.84 (VDD), U3.95 (VDDIO2), U3.106 (VDDUSB), U3.108 (VDD), U3.121 (VDD), U3.131 (VDDIO2), U3.144 (VDD), Y2.1 (OE), Y2.2 (VCC_1), Y2.3 (VCC_2), Y3.4 (VDD); also elsewhere on the board
/Connectors/BOOM_CTRL_1: R16.2; also elsewhere on the board
/Connectors/BOOM_CTRL_2: R17.2; also elsewhere on the board
/Connectors/BOOM_CTRL_3: R100.2; also elsewhere on the board
/Connectors/BOOM_CTRL_4: R101.2; also elsewhere on the board
/Connectors/CAM_EN: R15.2; also elsewhere on the board
/Connectors/DEBUG_LED: R44.1, U3.1 (PE2); also elsewhere on the board
/Connectors/GPS_PPS: R18.1; also elsewhere on the board
/Connectors/MISO_LPUART1_RX: R36.1, R47.2; also elsewhere on the board
/Connectors/MISO_UART4_RX: R14.2; also elsewhere on the board
/Connectors/MISO_UART5_RX: R26.1; also elsewhere on the board
/Connectors/MISO_USART3_RX: R22.2; also elsewhere on the board
/Connectors/MOSI_LPUART1_TX: R35.2; also elsewhere on the board
/Connectors/MOSI_UART4_TX: R13.2; also elsewhere on the board
/Connectors/MOSI_UART5_TX: R23.2; also elsewhere on the board
/Connectors/MOSI_USART3_TX: R21.2; also elsewhere on the board
/Connectors/RBF_1: U3.75 (PB14); also elsewhere on the board
/Connectors/STM32_NRST: C23.1, R48.1, U3.25 (NRST); also elsewhere on the board
/Connectors/STM32_SWCLK: U3.109 (PA14); also elsewhere on the board
/Connectors/STM32_SWDIO: U3.105 (PA13); also elsewhere on the board
/Connectors/STM32_SWO: U3.133 (PB3); also elsewhere on the board
/Connectors/VBAT_MONITOR: U3.28 (PC2); also elsewhere on the board
/MPI/MISO_MPI_RX_NEN: R33.2; also elsewhere on the board
/MPI/MISO_USART1_RX: R20.2; also elsewhere on the board
/MPI/MOSI_MPI_TX_EN: R34.2; also elsewhere on the board
/MPI/MOSI_USART1_TX: R19.2; also elsewhere on the board
/Memory/SPI_FLASH_MISO: R27.1; also elsewhere on the board
/Memory/SPI_FLASH_MOSI: R28.1; also elsewhere on the board
/Memory/SPI_FLASH_SCLK: R25.1; also elsewhere on the board
/Memory/SPI_NCS_FLASH_0: R37.2; also elsewhere on the board
/Memory/SPI_NCS_FLASH_1: R31.2; also elsewhere on the board
/Memory/SPI_NCS_FLASH_2: R32.2; also elsewhere on the board
/Memory/SPI_NCS_FLASH_3: R38.2; also elsewhere on the board
/RP2040/SPI1_CS0: R24.1; also elsewhere on the board
/RP2040/SPI1_RX: R41.2; also elsewhere on the board
/RP2040/SPI1_SCK: R39.2; also elsewhere on the board
/RP2040/SPI1_TX: R40.2; also elsewhere on the board
/STM32/BOOT0: C26.1, R49.1, U3.138 (PH3)
/STM32/I2C1_SCL: R91.1, U3.129 (PG14); also elsewhere on the board
/STM32/I2C1_SDA: R84.1, U3.128 (PG13); also elsewhere on the board
/STM32/I2C2_SCL: R42.1, U3.11 (PF1); also elsewhere on the board
/STM32/I2C2_SDA: R43.1, U3.10 (PF0); also elsewhere on the board
/STM32/I2C3_SCL: IC1.1 (SCL), R11.2, U3.26 (PC0)
/STM32/I2C3_SDA: IC1.6 (SDA), R12.2, U3.27 (PC1)
/STM32/I2C4_SCL: R92.1, U3.81 (PD12); also elsewhere on the board
/STM32/I2C4_SDA: R93.1, U3.82 (PD13); also elsewhere on the board
/STM32/OSC32_IN: U3.8 (PC14), Y2.4 (OUT)
/STM32/OSC_IN: C29.1, U3.23 (PH0), Y3.3 (OUTPUT)
GND: C15.2, C16.2, C17.2, C18.2, C19.2, C20.2, C21.2, C22.2, C23.2, C24.2, C25.2, C26.2, C27.2, C28.2, C29.2, C30.2, C31.2, C32.2, C33.2, C34.2, C35.2, D1.1 (K), D2.1 (K), D3.1 (K), IC1.4 (ADDR), IC1.5 (GND), R49.2, SW1.2, U3.16 (VSS), U3.30 (VSSA), U3.31 (VREF-), U3.38 (VSS), U3.51 (VSS), U3.61 (VSS), U3.71 (VSS), U3.83 (VSS), U3.94 (VSS), U3.107 (VSS), U3.120 (VSS), U3.130 (VSS), U3.143 (VSS), Y2.5 (GND_1), Y2.7 (GND_2), Y2.8 (GND_3), Y2.9 (GND_4), Y3.2 (GND); also elsewhere on the board
unnamed: D1.2 (A), R44.2
unnamed: D2.2 (A), R45.2
unnamed: D3.2 (A), R46.2
unnamed: R48.2, SW1.1
unnamed: R13.1, U3.34 (PA0)
unnamed: R14.1, U3.35 (PA1)
unnamed: R15.1, U3.36 (PA2)
unnamed: R16.1, U3.37 (PA3)
unnamed: R17.1, U3.40 (PA4)
unnamed: R100.1, U3.41 (PA5)
unnamed: R18.2, U3.42 (PA6)
unnamed: R101.1, U3.43 (PA7)
unnamed: R19.1, U3.101 (PA9)
unnamed: R20.1, U3.102 (PA10)
unnamed: R24.2, U3.110 (PA15)
unnamed: R21.1, U3.44 (PC4)
unnamed 168: R22.1, U3.45 (PC5); also elsewhere on the board
unnamed: R23.1, U3.113 (PC12)
unnamed: R25.2, U3.115 (PD1)
unnamed: R26.2, U3.116 (PD2)
unnamed: R27.2, U3.117 (PD3)
unnamed: R28.2, U3.118 (PD4)
unnamed: R29.1, U3.119 (PD5)
unnamed: R30.1, U3.122 (PD6)
unnamed: R45.1, U3.2 (PE3)
unnamed: R46.1, U3.3 (PE4)
unnamed: R38.1, U3.58 (PE7)
unnamed: R39.1, U3.66 (PE13)
unnamed: R40.1, U3.67 (PE14)
unnamed: R41.1, U3.68 (PE15)
unnamed: R37.1, U3.55 (PF15)
unnamed: R31.1, U3.56 (PG0)
unnamed: R32.1, U3.57 (PG1)
unnamed: R33.1, U3.89 (PG4)
unnamed: R34.1, U3.90 (PG5)
unnamed: R35.1, U3.92 (PG7)
unnamed: R36.2, U3.93 (PG8)

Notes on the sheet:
Optical Downlink not connected
32kHz Clock
25MHz Clock
VF = 2.2V
STM32 Reset Switch
Tri-state NC = Active
Make sure capacitors are close to pins
Pd = 44mW
*For all LEDs*
Temperature Sensor
iF = 20mA

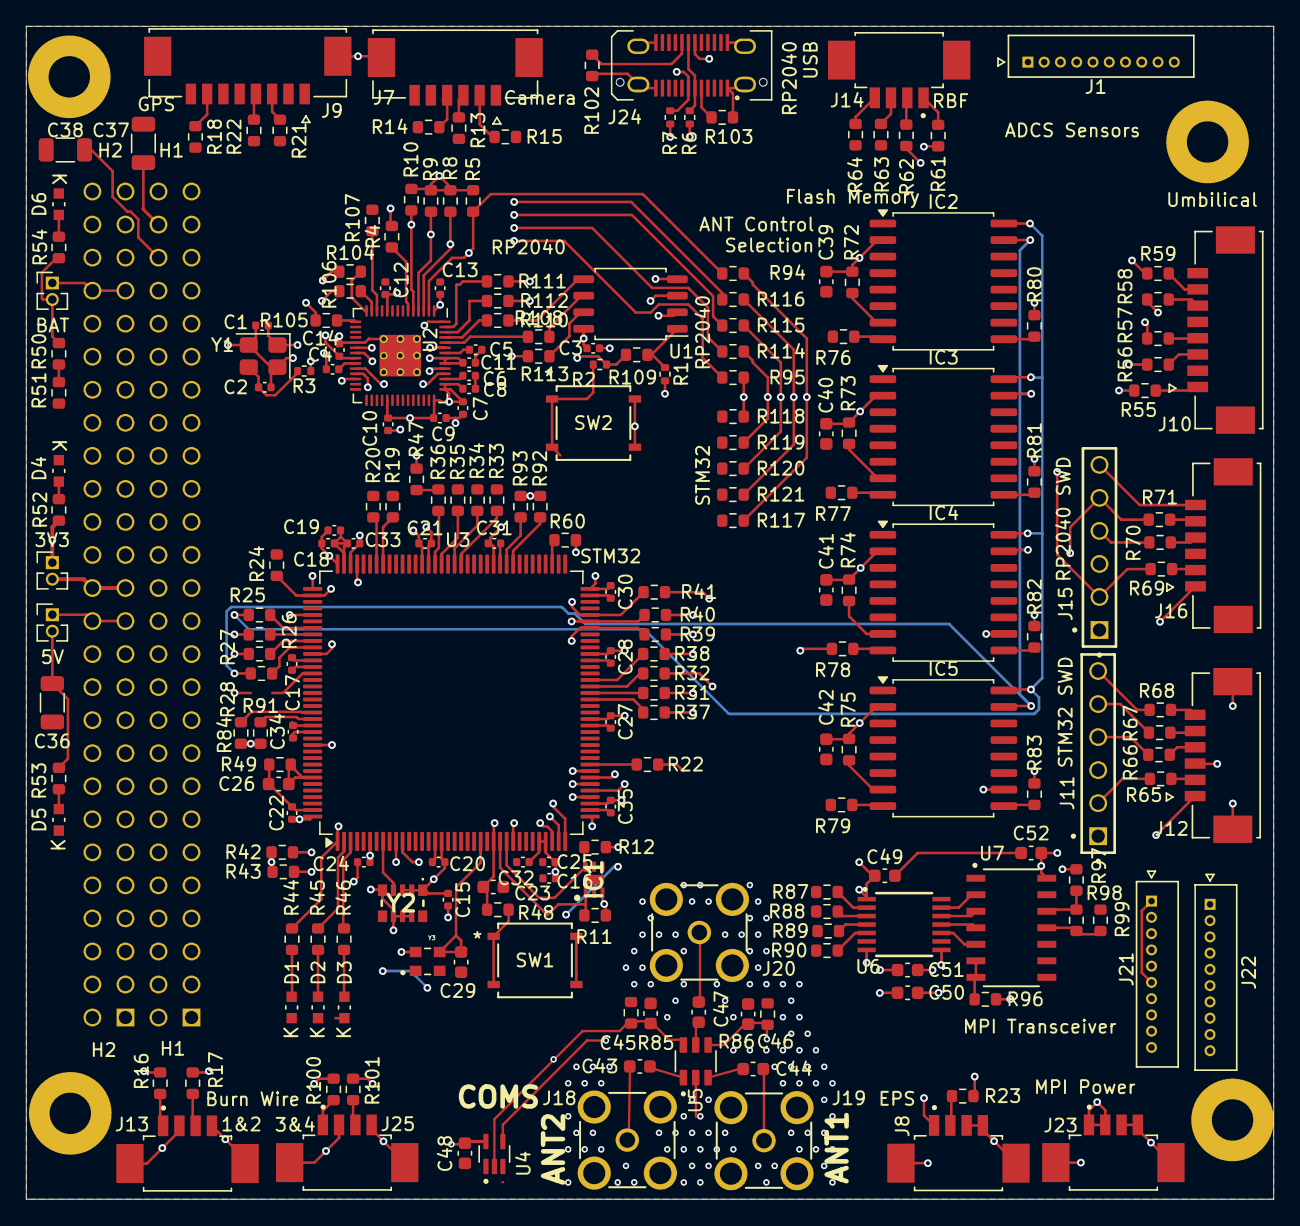
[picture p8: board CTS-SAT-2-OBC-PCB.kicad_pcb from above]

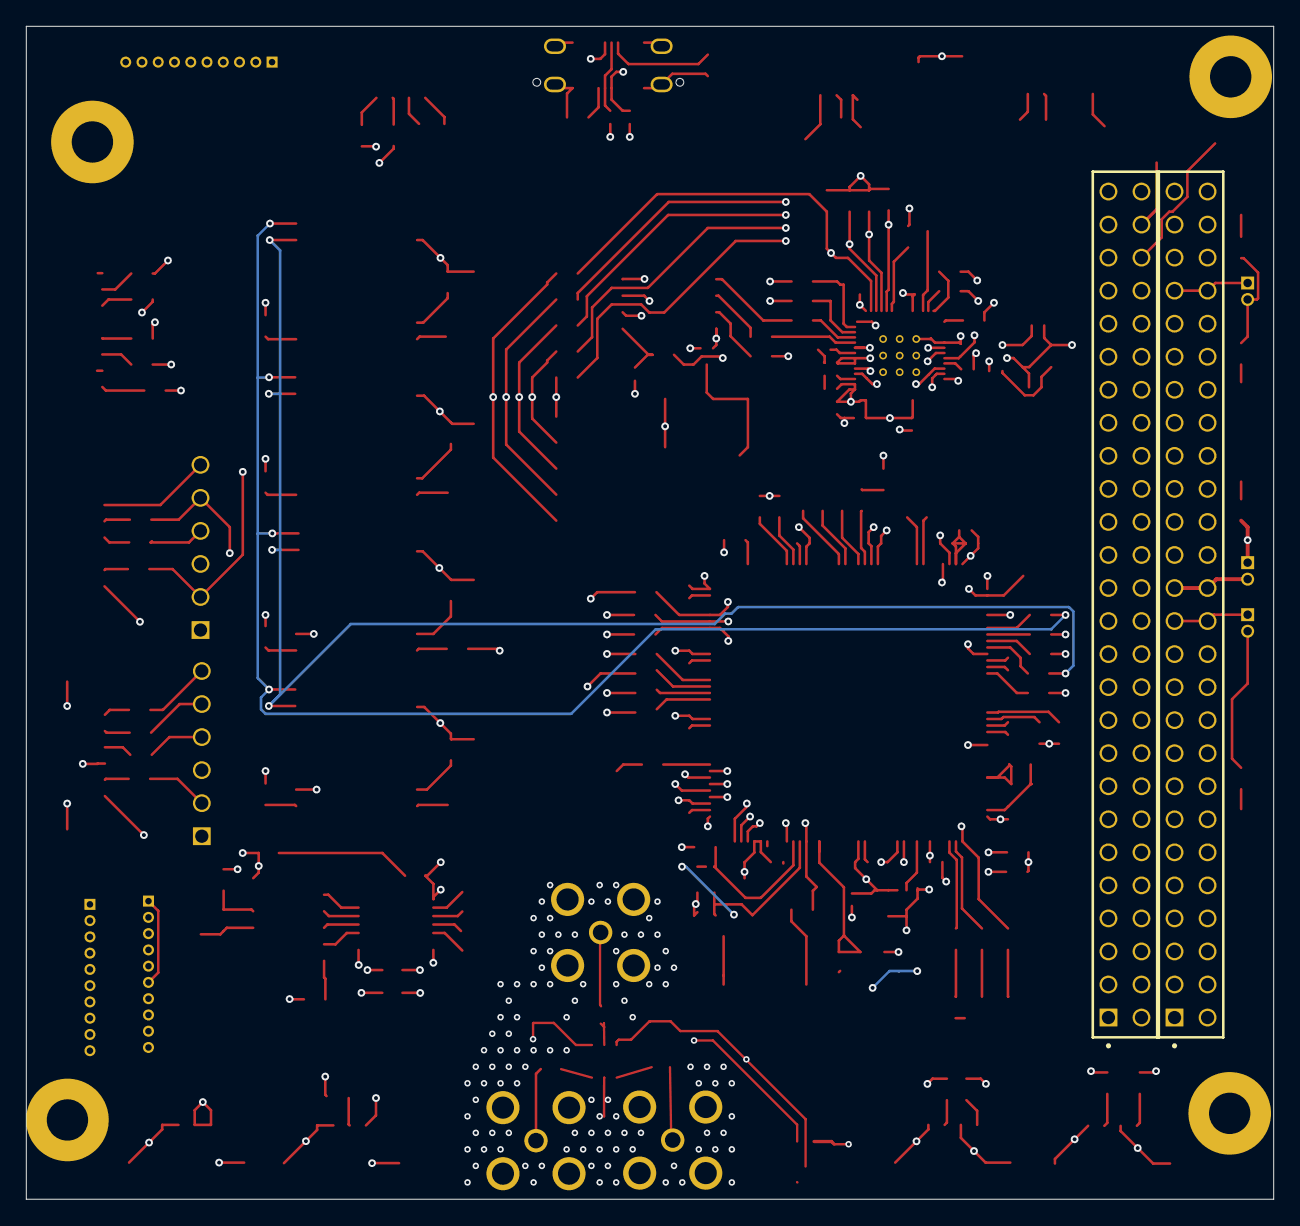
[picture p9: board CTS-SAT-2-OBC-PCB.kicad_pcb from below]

Board: 6 copper layers, 95.9 x 90.2 mm, 223 parts (2 on the bottom side), 182 nets.

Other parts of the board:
*1, *2, *3, *4: PC104 Mounting; PC104 MOUNTING POINTS
R22#2: 0R; R_0603_1608Metric

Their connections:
/Connectors/MISO_USART3_RX: R22#2.2; also elsewhere on the board
unnamed 168: R22#2.1; also elsewhere on the board

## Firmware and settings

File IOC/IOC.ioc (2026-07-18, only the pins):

Mcu.UserName=STM32L4R5ZITx
PA0.GPIO_Label=PIN_CAMERA_MOSI_UART4_TX
PA0.Signal=UART4_TX
PA1.GPIO_Label=PIN_CAMERA_MISO_UART4_RX
PA1.Signal=UART4_RX
PA10.GPIO_Label=PIN_MPI_MISO_USART1_RX
PA10.Signal=USART1_RX
PA2.Signal=ADCx_IN7
PA3.Signal=ADCx_IN8
PA4.Signal=ADCx_IN9
PA5.Signal=ADCx_IN10
PA6.Signal=ADCx_IN11
PA7.Signal=ADCx_IN12
PA9.GPIO_Label=PIN_MPI_MOSI_USART1_TX
PA9.Signal=USART1_TX
PB0.Signal=ADCx_IN15
PB1.Signal=ADCx_IN16
PB12.GPIO_Label=PIN_UHF_CTRL_OUT
PB12.Signal=GPIO_Output
PB14.GPIO_Label=PIN_REMOVE_BEFORE_FLIGHT_LOW_IS_FLYING_IN
PB14.Signal=GPIO_Input
PB2.GPIO_Label=PIN_BOOM_DEPLOY_EN_1_OUT
PB2.Signal=GPIO_Output
PB7.GPIO_Label=PIN_LED_DEVKIT_LD2
PB7.Signal=GPIO_Output
PC0.GPIO_Label=PIN_ANTENNA_B_I2C3_SCL
PC0.Signal=I2C3_SCL
PC1.GPIO_Label=PIN_ANTENNA_B_I2C3_SDA
PC1.Signal=I2C3_SDA
PC12.GPIO_Label=PIN_EPS_MOSI_UART_TX
PC12.Signal=UART5_TX
PC2.GPIO_Label=PIN_ADC_READ_VBAT_VOLTAGE
PC2.Signal=ADCx_IN3
PC3.Signal=ADCx_IN4
PC4.GPIO_Label=PIN_GNSS_MOSI_USART3_TX
PC4.Signal=USART3_TX
PC5.GPIO_Label=PIN_GNSS_MISO_USART3_RX
PC5.Signal=USART3_RX
PD1.GPIO_Label=PIN_MEM_SPI2_SCK
PD1.Signal=SPI2_SCK
PD12.GPIO_Label=PIN_TEMP_SENSOR_I2C4_SCL
PD12.Signal=I2C4_SCL
PD13.GPIO_Label=PIN_TEMP_SENSOR_I2C4_SDA
PD13.Signal=I2C4_SDA
PD2.GPIO_Label=PIN_EPS_MISO_UART_RX
PD2.Signal=UART5_RX
PD3.GPIO_Label=PIN_MEM_SPI2_MISO
PD3.Signal=SPI2_MISO
PD4.GPIO_Label=PIN_MEM_SPI2_MOSI
PD4.Signal=SPI2_MOSI
PD5.GPIO_Label=PIN_AX100_MISO_USART2_RX
PD5.Signal=USART2_TX
PD6.GPIO_Label=PIN_AX100_MOSI_USART2_TX
PD6.Signal=USART2_RX
PE10.Signal=GPIO_Output
PE13.GPIO_Label=PIN_RP2040_SPI1_SCLK
PE13.Signal=SPI1_SCK
PE14.GPIO_Label=PIN_RP2040_SPI1_MISO
PE14.Signal=SPI1_MISO
PE15.GPIO_Label=PIN_RP2040_SPI1_MOSI
PE15.Signal=SPI1_MOSI
PE2.GPIO_Label=PIN_LED_GP1_OUT
PE2.Signal=GPIO_Output
PE3.GPIO_Label=PIN_LED_GP2_OUT
PE3.Signal=GPIO_Output
PE4.GPIO_Label=PIN_LED_GP3_OUT
PE4.Signal=GPIO_Output
PE7.GPIO_Label=PIN_MEM_NCS_FLASH_0
PE7.Signal=GPIO_Output
PE8.GPIO_Label=PIN_MEM_NCS_FRAM_1
PE8.Signal=GPIO_Output
PE9.GPIO_Label=PIN_MEM_NCS_FRAM_0
PE9.Signal=GPIO_Output
PF0.GPIO_Label=PIN_ANTENNA_A_I2C2_SDA
PF0.Signal=I2C2_SDA
PF1.GPIO_Label=PIN_ANTENNA_A_I2C2_SCL
PF1.Signal=I2C2_SCL
PF10.GPIO_Label=PIN_CAM_EN_OUT
PF10.Signal=GPIO_Output
PF11.GPIO_Label=PIN_BOOM_DEPLOY_EN_2_OUT
PF11.Signal=GPIO_Output
PF12.GPIO_Label=PIN_BOOM_DEPLOY_EN_3_OUT
PF12.Signal=GPIO_Output
PF13.GPIO_Label=PIN_GNSS_PPS_IN
PF13.Signal=GPXTI13
PF14.GPIO_Label=PIN_BOOM_DEPLOY_EN_4_OUT
PF14.Signal=GPIO_Output
PF15.GPIO_Label=PIN_MEM_NCS_FLASH_3
PF15.Signal=GPIO_Output
PG0.GPIO_Label=PIN_MEM_NCS_FLASH_2
PG0.Signal=GPIO_Output
PG1.GPIO_Label=PIN_MEM_NCS_FLASH_1
PG1.Signal=GPIO_Output
PG13.GPIO_Label=PIN_STACK_I2C1_SDA
PG13.Signal=I2C1_SDA
PG14.GPIO_Label=PIN_STACK_I2C1_SCL
PG14.Signal=I2C1_SCL
PG4.GPIO_Label=PIN_MPI_NEN_RX_MISO_OUT
PG4.Signal=GPIO_Output
PG5.GPIO_Label=PIN_MPI_EN_TX_MOSI_OUT
PG5.Signal=GPIO_Output
PG7.GPIO_Label=PIN_DEBUG_MOSI_LPUART1_TX
PG7.Signal=LPUART1_TX
PG8.GPIO_Label=PIN_DEBUG_MISO_LPUART1_RX
PG8.Signal=LPUART1_RX
PH3-BOOT0.GPIO_Label=PIN_BOOT0
PH3-BOOT0.Signal=GPIO_Input

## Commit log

2026-01-10 Create KiCad project
    [CTS-SAT-2-OBC-PCB.kicad_pcb, CTS-SAT-2-OBC-PCB.kicad_sch]
2026-01-10 Add processor symbols to schematic
    [CTS-SAT-2-OBC-PCB.kicad_pcb, CTS-SAT-2-OBC-PCB.kicad_sch, RP2040.kicad_sch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]
2026-01-10 Connect RP2040, STM32, temperature sensor
    [CTS-SAT-2-OBC-PCB.kicad_sch, PC104.kicad_sch, RP2040.kicad_sch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]
2026-01-14 Add PC104 header sub-schematic
    [CTS-SAT-2-OBC-PCB.kicad_sch, PC104.kicad_sch, STM32.kicad_sch]
2026-01-17 Add STM32 I2C and SPI connections
    [CTS-SAT-2-OBC-PCB.kicad_sch, PC104.kicad_sch, STM32.kicad_sch]
2026-01-17 Add UARTs to STM32
    [CTS-SAT-2-OBC-PCB.kicad_sch, PC104.kicad_sch, STM32.kicad_sch]
2026-01-17 Add remaining STM32 connections
    [CTS-SAT-2-OBC-PCB.kicad_sch, STM32.kicad_sch, clock.kicad_sch]
2026-01-17 Assign SPI1 to Pi 4 <--> STM32
    [CTS-SAT-2-OBC-PCB.kicad_sch, PC104.kicad_sch, RP2040.kicad_sch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]
2026-01-21 Small updates
    [CTS-SAT-2-OBC-PCB.kicad_sch, PC104.kicad_sch, STM32.kicad_sch]
2026-01-21 Fix RP2040 1V1
    [RP2040.kicad_sch]
2026-01-24 RP2040 Schematic
    [CTS-SAT-2-OBC-PCB.kicad_sch, PC104.kicad_sch, RP2040.kicad_sch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]
2026-01-24 Add fast clock
    [CTS-SAT-2-OBC-PCB.kicad_sch, PC104.kicad_sch, RP2040.kicad_sch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]
2026-01-24 minor fix
    [CTS-SAT-2-OBC-PCB.kicad_sch]
2026-01-29 STM32 Flash Memory
    [PC104.kicad_sch, STM32.kicad_sch, stm32_flash.kicad_sch]
2026-01-30 STM32 RTC
    [CTS-SAT-2-OBC-PCB.kicad_sch, PC104.kicad_sch, STM32.kicad_sch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]
2026-01-30 prepare for FRAM
    [CTS-SAT-2-OBC-PCB.kicad_sch, stm32_flash.kicad_sch]
2026-01-31 Begin with connectors
    [CTS-SAT-2-OBC-PCB.kicad_sch, PC104.kicad_sch, connectors.kicad_sch]
2026-02-04 Import CTS-SAT-1 PCB
    [Antenna and LoRa.kicad_sch, CTS-SAT-2-OBC-PCB.kicad_sch, External Connectors.kicad_sch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]
2026-02-04 Remove extraneous objects
    Removed: FRAM, PC104 pull-downs, Altium data
    [External Connectors.kicad_sch]
2026-02-04 Begin importing to SAT-2 PCB
    [CTS-SAT-2-OBC-PCB.kicad_sch, PC104.kicad_sch, antenna.kicad_sch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]
2026-02-07 Connect connectors
    [CTS-SAT-2-OBC-PCB.kicad_sch, PC104.kicad_sch, RP2040.kicad_sch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]
2026-02-07 Add STM32 Reset Switch & RP2040 I2C pins
    [CTS-SAT-2-OBC-PCB.kicad_sch, PC104.kicad_sch, RP2040.kicad_sch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]
2026-02-07 Move ANT to RP2040
    [CTS-SAT-2-OBC-PCB.kicad_sch, RP2040.kicad_sch, STM32.kicad_sch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]
2026-02-07 Add RP2040 SWD
    [CTS-SAT-2-OBC-PCB.kicad_sch, PC104.kicad_sch, RP2040.kicad_sch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]
2026-02-13 Finish schematic v1
    [CTS-SAT-2-OBC-PCB.kicad_sch, PC104.kicad_sch, RP2040.kicad_sch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]
2026-02-13 Fix RP2040 BOOTSEL
    [PC104.kicad_sch, RP2040.kicad_sch]
2026-02-17 Add IOC and second burnwire connector
    [CTS-SAT-2-OBC-PCB.kicad_sch, PC104.kicad_sch, STM32.kicad_sch]
2026-02-21 Prepare for layout
    [CTS-SAT-2-OBC-PCB.kicad_pcb]
2026-02-28 Assign footprints
    [CTS-SAT-2-OBC-PCB.kicad_pcb, PC104.kicad_sch, RP2040.kicad_sch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]
2026-02-28 Update USB connector to USBC
    [RP2040.kicad_sch]
2026-02-28 Add USBC pull-downs
    [RP2040.kicad_sch]
2026-03-07 Basic board shape
    [CTS-SAT-2-OBC-PCB.kicad_pcb]
2026-03-07 Fix diode footprint assignments
    [CTS-SAT-2-OBC-PCB.kicad_pcb, PC104.kicad_sch, STM32.kicad_sch]
2026-03-07 Place connectors
    [CTS-SAT-2-OBC-PCB.kicad_pcb]
2026-03-11 Resistors for connectors
    [CTS-SAT-2-OBC-PCB.kicad_pcb]
2026-03-14 make most changes from design review
    [CTS-SAT-2-OBC-PCB.kicad_pcb, RP2040.kicad_sch, STM32.kicad_sch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]
2026-03-14 H1/2 capacitors and LEDs
    [CTS-SAT-2-OBC-PCB.kicad_pcb, PC104.kicad_sch, mpi.kicad_sch]
2026-03-14 STM32 capacitors
    [CTS-SAT-2-OBC-PCB.kicad_pcb, PC104.kicad_sch]
2026-04-08 Place RP2040
    [CTS-SAT-2-OBC-PCB.kicad_pcb, RP2040.kicad_sch]
2026-04-08 RP2040 Peripherals
    [CTS-SAT-2-OBC-PCB.kicad_pcb]
2026-04-08 minor labels
    [CTS-SAT-2-OBC-PCB.kicad_pcb]
2026-04-11 MPI layout
    [CTS-SAT-2-OBC-PCB.kicad_pcb, RP2040.kicad_sch, mpi.kicad_sch]
2026-04-11 Layout Revision 1
    [CTS-SAT-2-OBC-PCB.kicad_pcb]
2026-04-11 Refill zones
    [CTS-SAT-2-OBC-PCB.kicad_pcb]
2026-04-11 Add NC pins
    [PC104.kicad_sch, RP2040.kicad_sch, STM32.kicad_sch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]
2026-05-23 3V3 plane
    [PC104.kicad_sch]
2026-05-23 Begin routing
    [CTS-SAT-2-OBC-PCB.kicad_pcb, PC104.kicad_sch]
2026-05-23 Continue routing
    [CTS-SAT-2-OBC-PCB.kicad_pcb]
2026-06-06 Replace Optical Downlink with ADCS Sensors connector
    [CTS-SAT-2-OBC-PCB.kicad_pcb, PC104.kicad_sch, STM32.kicad_sch]
2026-06-06 Update schematic to allow using STM32 alone
    [CTS-SAT-2-OBC-PCB.kicad_pcb, CTS-SAT-2-OBC-PCB.kicad_sch, PC104.kicad_sch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]
2026-06-06 Adjust Comms layout
    [CTS-SAT-2-OBC-PCB.kicad_pcb]
2026-06-06 minor routing change for comms
    [CTS-SAT-2-OBC-PCB.kicad_pcb]
2026-06-13 Populate more resistors
    [CTS-SAT-2-OBC-PCB.kicad_pcb, CTS-SAT-2-OBC-PCB.kicad_sch, STM32.kicad_sch]
2026-06-13 3V3 routing
    [CTS-SAT-2-OBC-PCB.kicad_pcb]
2026-06-20 Reroute power
    [CTS-SAT-2-OBC-PCB.kicad_pcb, antenna.kicad_sch, mpi.kicad_sch]
2026-06-20 route most connectors
    [CTS-SAT-2-OBC-PCB.kicad_sch, PC104.kicad_sch, STM32.kicad_sch]
2026-07-11 Enable ADC channels on IOC
2026-07-11 Adjust schematic for new ADC pins
    [STM32.kicad_sch]
2026-07-11 rearrange board
2026-07-18 Added GPIO_Output pin for UHF
2026-07-18 finish routing!
    [STM32.kicad_sch]
2026-07-22 DRC fixes
    Clearance errors as well as schematic convention
    [antenna.kicad_sch]
2026-07-25 Fix the switches
    [RP2040.kicad_sch, STM32.kicad_sch]
2026-07-25 fix other switch
2026-07-25 Remove disconnected traces and pads
